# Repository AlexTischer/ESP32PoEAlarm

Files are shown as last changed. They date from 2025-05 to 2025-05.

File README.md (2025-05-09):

# ESP32 PoE Alarm Board

This repository contains all files related to the ESP32-Alarm board project.

## Project Structure

- **Docs/**  
  Project documentation (LaTeX sources, images, generated PDFs, etc.).

- **Resources/**  
  Manuals, datasheets, reference images, and other useful materials.

- **alarm.yaml**  
  Main ESPHome configuration file, defining the firmware behavior for the ESP32.

- **Case v2.step**  
  3D model of the enclosure for the board.

- **ESP32_Alarm_PCB.kicad_sch**  
  Electrical schematic of the board, created with KiCad.

- **ESP32_Alarm_PCB.kicad_pcb**  
  PCB layout of the board, created with KiCad.

- **ESP32_Alarm_PCB.kicad_pro / .kicad_prl / .kicad_dru**  
  KiCad project files and design rule settings.

- **ESP32_Alarm_PCB.step**  
  3D model of the PCB for mechanical integration and visualization.

- **production/**  
  Folder containing production files such as netlists and fabrication archives.

- **ESP32-POE/**  
  Custom KiCad libraries, footprints, and symbols, including modules and screw terminals.

- **ESP32_Alarm_PCB-backups/**  
  Automatic backups of KiCad project files.

- **fabrication-toolkit-options.json**  
  Options for PCB fabrication toolkit and production file generation.

## Notes

- All KiCad project files are compatible with version 8.0 or newer.
- To build and upload the firmware, edit and use `alarm.yaml` with ESPHome.

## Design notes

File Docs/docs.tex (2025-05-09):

\documentclass[a4paper,12pt]{article}

\usepackage[utf8]{inputenc}
\usepackage[T1]{fontenc}
\usepackage[hidelinks]{hyperref}
\usepackage{cite}
\usepackage{listings}
\usepackage{xcolor}
\usepackage{graphicx}
\usepackage{float}
\usepackage{subfig}

\title{Esp32 PoE Alarm Board}
\author{Alessandro Tischer}
\date{\today}

\begin{document}
\maketitle

\newpage
\tableofcontents
\newpage

\section{Introduction}
The aim of this project is to design and develop a Power over Ethernet (PoE) system based on the ESP32 microcontroller \cite{ESP32WiFiBluetooth}, which serves both as an alarm system and as a platform for integrating sensors and actuators into a home automation system.  
The board will communicate via Ethernet with a Home Assistant \cite{assistantHomeAssistant} server, which will manage the alarm system logic and provide centralized control for home automation.  

\subsection{Main Objectives}\label{sec:MainObjectives}
The main objectives are:
\begin{itemize}
    \item Provide reliable detection of state changes of multiple digital and analog inputs such as:
        \begin{itemize}
            \item reed switches for door/window opening,
            \item radar sensors for presence detection,
            \item PIR sensors for motion detection,
            \item gas sensors for gas leak detection,
            \item water level sensors for water leak detection,
        \end{itemize}
    \item Control devices such as sirens and strobe lights by turning them on or off.
    \item Ensure less than a second of latency for sensing and controlling devices. 
    \item Ensure seamless integration with Home Assistant for centralized management and automation.
    \item Guarantee high reliability and continuous operation, even in case of network or power issues.
    \item Allow easy installation, configuration, and future expansion with additional modules or sensors.
    \item Maintain data security and privacy keeping everything local.
    \item Ensure the board is cost-effective and made with readily available components.
\end{itemize}

\subsection{Hardware features}
Key features of the board include:
\begin{itemize}
    \item 16 digital input channels for sensor monitoring,
    \item 2 relay outputs for controlling alarm devices,
    \item 6 analog/digital general-purpose pins for smart sensors or future expansions,
    \item I\textsuperscript{2}C port for additional modules,
    \item Multiple 3V, 5V, and GND pins for powering external devices and expansions.
    \item Power over Ethernet (PoE) support for powering the board and connected devices.
    \item Ethernet connectivity for reliable communication.
\end{itemize}

\newpage
\section{Hardware Structure}
The project is built around a custom PCB designed to accommodate the microcontroller's development board. 

\subsection{Microcontroller}
The ESP32 microcontroller is the heart of the board, providing the necessary processing power and connectivity options. In particular, an Olimex ESP32-POE board \cite{olimexESP32POEOpenSource} was chosen for this project, since it is a low-cost, open-source board with built-in PoE support, which simplifies the design and reduces the number of components needed in the PCB. 

\subsection{Power Supply}
The Olimex ESP32-POE is equipped with a LiPo battery connector and charger, which allows the board to be powered by a battery in case of power failure (even though this won't be likely to happen in the scenario this board was first designed for since the board will be powered by a PoE switch that is connected to a UPS). The battery is charged when the board is powered by PoE, and its voltage can be monitored by the microcontroller. 
This specific development board was chosen against its ISO version, the ESP32-POE-ISO, which has an isolated PoE module. The reason for this choice is that the ISO version is a little bit more expensive, and has a lower power budget. The non ISO version, in fact, can output up to 4W of power to external devices via its 3.3V and 5V pins. This is useful for powering sensors and other devices connected to the board, without the need for additional power supplies. 

\subsection{Logic input/output operations}
The large number of required digital input/outputs could not be satisfied by the Olimex ESP32-POE board alone, as several of its GPIO pins are reserved for the PoE module, reset, and other functions. Two main solutions were considered:
\begin{itemize}
    \item The use of a GPIO expander, such as the MCP23017 \cite{MCP23017}, which communicates with the ESP32 via I\textsuperscript{2}C. This approach is highly flexible and allows for the addition of further GPIOs with minimal changes to the design. However, it requires additional components, a more complex design, and limits the expanded I/Os to digital operations only.
    \item The use of a diode matrix connected to the available GPIOs. This solution enables the utilization of all available GPIOs on the Olimex board, supporting both digital and analog operations. Its drawbacks include increased software complexity, more demanding soldering operations, and a limitation to a maximum of 36 I/Os (using all 12 available GPIOs for the matrix) or 16 I/Os (using 8 GPIOs).
\end{itemize}

The first solution was chosen, as it is easier to implement and the lack of analog functionality on the additional I/Os is not a limitation for this project. For example, reed switch sensors are digital-only, and many other sensors can operate in a simple mode where a pin is pulled high or low depending on the sensor state. Furthermore, the GPIO expander requires only two GPIOs for operation, leaving the remaining pins available for other purposes, such as analog functions or digital communication protocols (e.g., I\textsuperscript{2}C, UART, or SPI). Finally, the I\textsuperscript{2}C bus used for communication with the GPIO expander can be shared with other I\textsuperscript{2}C devices.

\subsection{Relay outputs}
The board features two relay outputs, which can be used to control devices such as sirens or strobe lights. The relays are controlled by the ESP32 GPIOs and can be activated or deactivated based on the state of the inputs or commands received from Home Assistant. The relays chosen for this project are the Omron G5V-1-DC5 \cite{G5V1DC5}, which are compact and suitable for low-power applications.
These relays are designed for low-voltage DC and AC applications, making them ideal for controlling alarm devices. They have a coil voltage of 5VDC and can be activated with a current of 30mA. The relays can switch loads up to 1A at 24V DC or 0.5A at 125V AC, providing sufficient power for most alarm devices.

\newpage
\section{Software Structure}
The software for the ESP32 PoE Alarm Board is developed using ESPHome \cite{ESPHomeSmartHome}, an open-source platform designed for creating custom firmware for microcontrollers. ESPHome provides a highly modular and configurable framework, enabling seamless integration with Home Assistant.

\subsection{Configuration File}
The core of the software is a YAML configuration file, which defines the behavior and features of the board. 

\subsubsection{Device and Platform Settings}
Identification of the board, ESP32 platform, and framework type:

\begin{lstlisting}
    esphome:
      name: alarm
      friendly_name: Alarm

    esp32:
      board: esp32dev
      framework:
        type: arduino
\end{lstlisting}

\subsubsection{Networking}
Configuration of the Ethernet interface (LAN8720), including pin assignments and static IP address.

\begin{lstlisting}
    ethernet:
      type: LAN8720
      mdc_pin: GPIO23
      mdio_pin: GPIO18
      power_pin: GPIO5
      phy_addr: 0
      ip_address: 192.168.1.254
\end{lstlisting}

\subsubsection{Communication}
Enabling of the Home Assistant API, web server, and logging for integration and diagnostics.

\begin{lstlisting}
    logger:

    api:
      encryption:
        key: "{REDACTED}"
      reboot_timeout: 0s

    web_server:
    port: 80
\end{lstlisting}

\subsubsection{I\textsuperscript{2}C Bus}
Definition of the I\textsuperscript{2}C bus for communication with external devices.

\begin{lstlisting}
    i2c:
      sda: GPIO16
      scl: GPIO13
      scan: true
      id: bus_a
\end{lstlisting}

\subsubsection{GPIO Expander}
Configuration of the MCP23017 I/O expander, including its I\textsuperscript{2}C address.

\begin{lstlisting}
    mcp23017:   
      - id: 'mcp23017_hub'
        address: 0x20
\end{lstlisting}

\subsubsection{Inputs}
Declaration of 16 binary sensors connected to the MCP23017, each mapped to a specific pin and configured with pull-up resistors. Only the first will be reported here.

\begin{lstlisting}
    binary_sensor:
      - platform: gpio
        name: "MCP23017 Pin A0"
        pin:
            mcp23xxx: mcp23017_hub
            number: 0
            mode:
            input: true
            pullup: true
            inverted: false
\end{lstlisting}

\subsubsection{Outputs}
Definition of two relay switches, each mapped to a dedicated ESP32 GPIO pin. Only the first will be reported here.

\begin{lstlisting}
    switch:
      - platform: gpio
        name: "Relay1"
        id: relay1
        pin: GPIO32
\end{lstlisting}

\subsubsection{OTA Updates}
Enabling of over-the-air firmware updates with password protection.

\begin{lstlisting}
    ota:
    - platform: esphome
        password: "{REDACTED}"
\end{lstlisting}

\subsection{Firmware Generation}
ESPHome compiles the YAML configuration into a binary firmware file, which is then uploaded to the ESP32 microcontroller. The firmware includes all necessary libraries and drivers for the ESP32, Ethernet, I\textsuperscript{2}C, and GPIO expander. The compilation process also generates a web interface for monitoring and controlling the board.

\subsection{Integration with Home Assistant}
The ESP32 PoE Alarm Board is designed to work seamlessly with Home Assistant. The integration is achieved through the Home Assistant API, which allows the board to send and receive state updates and commands. 
The board sends state updates for all connected sensors and inputs, enabling Home Assistant to monitor the system's status in real-time. Additionally, it can receive commands from Home Assistant to control the relay outputs, allowing for remote activation of alarm devices.

\subsection{Event Handling}
The firmware includes event handling capabilities to respond to state changes and commands. When a sensor state changes (e.g., a door opens or a motion is detected), the firmware generates an event that is sent to Home Assistant. Similarly, when a command is received from Home Assistant (e.g., activate a relay), the firmware processes the command and updates the relay state accordingly.
At this stage, the firmware does not include any logic for handling alarms onboard, as this functionality is designed to be managed by Home Assistant's "Alarmo" integration \cite{faberNielsfaberAlarmo2025}. However, the firmware is designed to be extensible, allowing for future enhancements such as local alarm logic or additional features.
ESPHome provides a well documented component for alarm systems, which can be used to implement local alarm logic in the future \cite{AlarmControlPanel}. This component allows for the definition of alarm states, triggers, and actions, enabling the board to operate independently of Home Assistant if needed.

\subsection{Runtime Behavior}
During operation, the firmware:
\begin{itemize}
    \item Continuously monitors the state of all connected sensors and inputs.
    \item Sends state updates to Home Assistant over the Ethernet connection.
    \item Executes commands received from Home Assistant, such as activating relays.
    \item Logs events and errors for debugging and maintenance purposes.
    \item Handles OTA updates, allowing for easy firmware upgrades without physical access to the board.
    \item Expose a web interface for monitoring and controlling the board, providing real-time status updates and configuration options.
\end{itemize}

This software architecture ensures a robust, flexible, and easily maintainable solution for the ESP32 PoE Alarm Board, meeting the project's objectives and providing a reliable foundation for future enhancements.

\newpage
\section{Sensors}
The board is designed to support a wide range of sensors. For the initial version, the following sensors were selected and tested:
\begin{itemize}
    \item \textbf{Reed Switches}: Used for door/window opening detection.
    \item \textbf{Radar Sensors}: Used for presence detection.
    \item \textbf{PIR Sensors}: Used for motion detection.
\end{itemize}

\subsection{Reed Switches}
Reed switches are simple magnetic sensors that close or open a circuit when exposed to a magnetic field. They are commonly used in security systems to detect the opening of doors or windows. The board supports multiple reed switches, each connected to a digital input pin on the GPIO expander. Since the MCP23017 GPIOs are configured with pull-up resistors, the reed switches are connected in a normally open configuration. When a door or window is opened, the magnetic field is interrupted, causing the reed switch to close and pull the GPIO pin low.

\subsection{Radar Sensors}
For this application, LD2420 radar sensors were chosen \cite{HLKLD242024GhzHumana}. These sensors are capable of detecting motion and presence in a wide area. They work by emitting microwave signals and measuring the reflection from nearby objects. The LD2420 sensors can work in both smart and dumb modes. In dumb mode, the sensor outputs a digital signal indicating the presence of a moving object. In smart mode, the sensor can provide additional information such as distance. To interface with the LD2420 sensors in dumb mode, the board uses a digital input pin on the GPIO expander, and powers the sensor via one of the 3.3V and GND pins.
To use the sensor in smart mode, it's possible to use one of the ESP32's pins to communicate with the sensor via UART. 

\subsection{PIR Sensors}
Passive Infrared (PIR) sensors are widely used for motion detection in security systems. They work by detecting changes in infrared radiation emitted by objects in their field of view. The board supports multiple PIR sensors, each connected to a digital input pin on the GPIO expander. Similar to the reed switches, the PIR sensors are connected in a normally open configuration, and the GPIO pins are configured with pull-up resistors. When motion is detected, the PIR sensor closes the circuit, pulling the GPIO pin low.

\newpage
\section{Design and Prototyping}
The design of the board was done using KiCAD, a free and open-source PCB design software \cite{KiCadEDA}.

\subsection{Schematic Design}
The first step in the design process was to create the schematic diagram of the board. The schematic includes all components and connections details. The main components in the schematic are:
\begin{itemize}
    \item ESP32 microcontroller
    \item GPIO expander
    \item Relays
    \item Screw terminals
    \item Transistors
    \item Diodes
    \item Resistors
\end{itemize}

It was possible to find a ready-made footprint and symbol for both the ESP32-POE board, the GPIO expander and the relays, other than all the other components that were built in KiCAD \cite{ESP32POEFootprintSymbol}. This greatly simplified the design process, as it was possible to focus on the connections and functionality of the board rather than creating custom components.

The GPIO expander was connected to the ESP32 via the I\textsuperscript{2}C bus, which uses two pins (SDA and SCL) for communication. The GPIO expander doesn't have pull-up resistors on its I\textsuperscript{2}C pins, so 2.2k$\Omega$ resistors were added between the SDA and SCL pins and VCC.
The expander also needs to be connected to 3.3V and GND.
The expander needs to be configured in hardware to have a specific I\textsuperscript{2}C address, which is done by connecting its address pins to either VCC or GND. In this case, the address was set to 0x00, connecting all the address pins to GND. 
Another connection that the GPIO expander allows is for the interrupt pins, which can be used to notify the ESP32 when a state change occurs on one of the GPIOs. In this case, since ESPHome doesn't support this feature, the interrupt pins were not connected to the ESP32.

The relays are connected to the ESP32 GPIOs through an NPN transistor (2n2222 \cite{PN2222ABU}), which acts as a switch to control the relay coil. The transistor is driven by the GPIO pin through a 1k$\Omega$ resistor, and when the pin is set high, it allows current to flow through the relay coil, activating the relay. A flyback diode (1N4007 \cite{1N4007}) is connected in parallel with the relay coil to protect the transistor from voltage spikes generated when the relay is deactivated.

The screw terminals are used to easily and firmly connect the sensors and devices to the board. Each terminal is connected to a specific GPIO pin on the GPIO expander, to a free GPIO pin on the microcontroller (or to a reusable one, such as the I\textsuperscript{2}C pins), to one of the three pins of each relay, to GND, to 3.3V, or to 5V. 

The following schematic shows the main components and connections of the board:
\begin{figure}[H]
    \centering
    
    \caption{Schematic of the ESP32 PoE Alarm Board}
    \label{fig:schematic}
\end{figure}

\subsection{Component Selection, BOM}
The components used in the design were selected based on their availability and compatibility with the project requirements. The complete Bill of Materials (BOM), for each board, includes:

\begin{itemize}
    \item n.1 Olimex ESP32-POE development board
    \item n.1 Microchip MCP23017 GPIO expander
    \item n.2 Omron G5V-1-DC5 relays
    \item n.2 2n2222 NPN transistors
    \item n.2 1N4007 diodes
    \item n.2 2.2k$\Omega$ resistors (for I\textsuperscript{2}C pull-ups)
    \item n.2 1k$\Omega$ resistors (for transistor base)
    \item n.1 DIP 28 pin socket (for the GPIO expander)
    \item n.2 female 2.54mm 10 pin sockets (for the ESP32)
    \item n.19 5.0mm 3 pin screw terminals
\end{itemize}

\subsection{Breadboard Prototyping}
Before creating the PCB, a breadboard prototype was built to test the design and functionality of the board. The breadboard prototype included all the main components, including the ESP32 microcontroller, GPIO expander, relays, and some of the screw terminals. The prototype was used to test the validity of the schematic design, the functionality of the components, and the capabilities of the integrated LDO regulator to power the board.

The breadboard prototype was also used to test the ESPHome configuration and the integration with Home Assistant. The GPIO expander was successfully configured, and the relays were tested to ensure they could be activated and deactivated correctly. The sensors were also connected to the board, and their state changes were monitored in Home Assistant.

Once the breadboard prototype was tested and validated, the design was ready for the PCB layout.

The following image shows the breadboard prototype of the board:
\begin{figure}[H]
    \centering
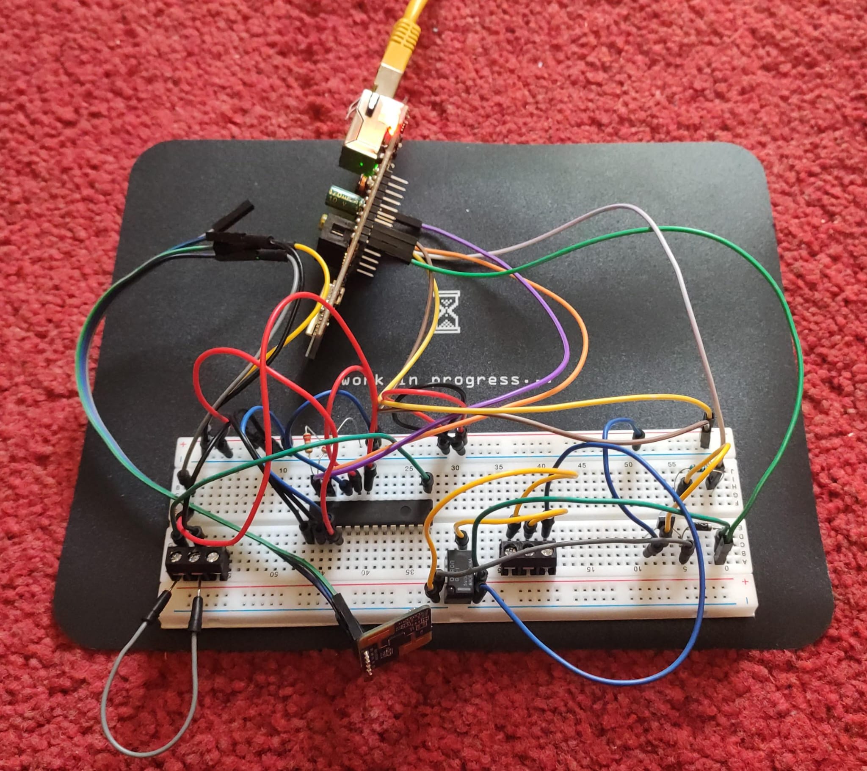
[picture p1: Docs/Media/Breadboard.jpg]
    
    \caption{Breadboard prototype of the ESP32 PoE Alarm Board}
    \label{fig:breadboard}
\end{figure}

\subsection{PCB Layout}

The PCB layout was created using KiCAD, following the schematic design. The layout includes all components, traces, and pads for soldering. The board was designed to be easy to assemble, to mount, to connect to the sensors and devices, to diagnose and repair.
Because of the last point, the board wasn't targeted to be as small as possible, but rather to have all the screw mounts for the sensors on the same side of the board. The other screw terminals are grouped by functionality on the other sides of the board.

All the used components are THD, which makes the soldering process easier and faster, given the low quantity of pieces to be produced. The GPIO expander and the ESP32 are mounted using sockets, which allows for easy replacement in case of failure. This also allow the ESP32 antenna to be further away from the board itself, which improves the signal quality, in case the board were to be used with Wi-Fi connectivity instead of Ethernet, or if ESP32 Bluetooth capabilities were to be exploited.

It was possible to fit all the traces and pads on a two-layer PCB, which was a requirement for the project to be cost-effective. 

The following image shows the PCB layout, with front side traces in red and back side traces in blue. 
\begin{figure}[H]
    \centering
    
    \caption{PCB layout of the ESP32 PoE Alarm Board}
    \label{fig:pcb}
\end{figure}

\subsection{PCB Manufacturing}

The PCB was designed to be manufactured using a low-cost PCB manufacturer, which allows for easy, fast and affordable production of the board and fast shipping \cite{PCBPrototypePCB}.

In KiCAD it is possible to generate the Gerber files needed for the PCB manufacturing, which include all the necessary information for the manufacturer to produce the board. The Gerber files were generated and sent to the manufacturer.

After a few days, the PCBs were received and inspected for any defects. The boards were found to be well manufactured, with no visible defects or issues, so the assembly process could begin.

The following image shows the manufactured PCB:
\begin{figure}[H]
    \centering
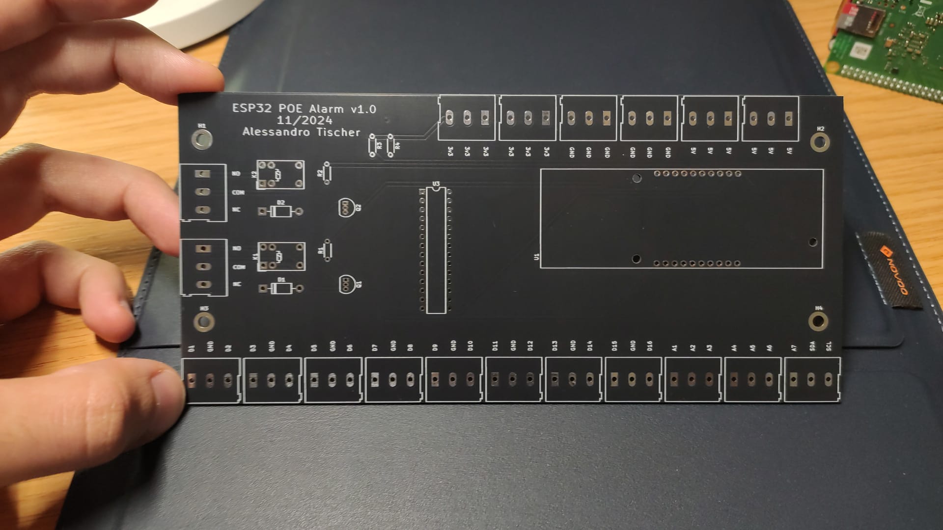
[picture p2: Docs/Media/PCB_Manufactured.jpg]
    
    \caption{Manufactured PCB of the ESP32 PoE Alarm Board}
    \label{fig:manufactured_pcb}
\end{figure}

\subsection{PCB Assembly}

The assembly process was done by hand, using a soldering iron and soldering wire. The components were soldered to the PCB according to the layout, starting with the smallest components and working up to the largest ones. 

Three boards were completely assembled: two for the final application, and one to be kept as a spare in case of failure.
The assembly process was straightforward, but required quite a bit of time and patience, to avoid shorts or cold solder joints.

The following image shows the assembled PCB:
\begin{figure}[H]
    \centering
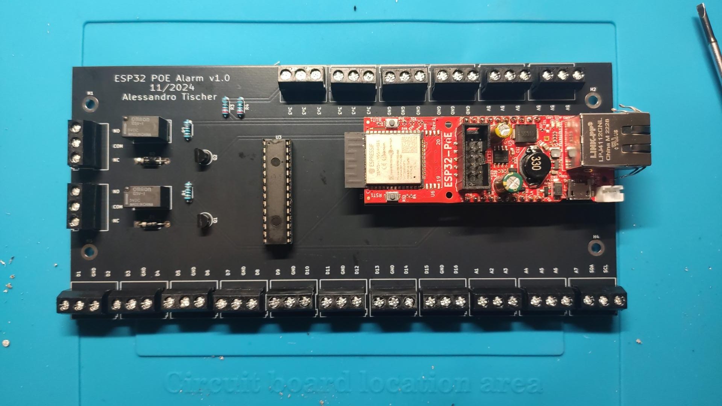
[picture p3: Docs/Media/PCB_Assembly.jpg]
    
    \caption{Assembled PCB of the ESP32 PoE Alarm Board}
    \label{fig:assembled_pcb}
\end{figure}

\newpage
\section{Testing and Validation}

The first testing phase on the complete boards was done to verify the correct operation of the components and the overall functionality of the board. The tests included:

\begin{itemize}
    \item \textbf{Power supply tests:} verifying that the board powers up correctly and that the voltage levels are within the specified range across all the board.
    \item \textbf{Ethernet tests:} verifying that the Ethernet connection is working correctly.
    \item \textbf{Web UI tests:} checking that the web interface is accessible and functional.
    \item \textbf{GPIO tests:} checking that the GPIO expander is communicating with the ESP32.
    \item \textbf{Relay tests:} verifying that the relays can be activated and deactivated correctly.
    \item \textbf{Sensor tests:} checking that the GPIOs could detect a short circuit to ground.
\end{itemize}

The second testing phase was designed to verify that all initial requirements, as defined in Section~\ref{sec:MainObjectives}, were met. Each test corresponds to a specific objective or feature of the board:

\begin{itemize}
    \item \textbf{Reliable detection of state changes:} The board was tested with various digital sensors (reed switches, radar sensors, PIR sensors) to ensure prompt and accurate detection of input changes.
    \item \textbf{Low latency:} The response time between a sensor state change and the corresponding update in Home Assistant is so short that it can barely be perceived, meeting the requirement for low latency.
    \item \textbf{Integration with Home Assistant:} The board was integrated with Home Assistant, and bidirectional communication (state updates and commands) was verified.
    \item \textbf{Reliability and continuous operation:} The board was operated continuously for several days, powered via PoE and connected to a UPS, without any failures or missed events.
    \item \textbf{Ease of installation and expansion:} The modular design, use of screw terminals, and I\textsuperscript{2}C expandability were validated during assembly and sensor connection.
    \item \textbf{Data security and privacy:} Using ESPHome and Home Assistant, the board was configured to operate locally without external cloud services, ensuring intrinsic data security and privacy.
\end{itemize}

All tests were successful, confirming that the ESP32 PoE Alarm Board meets the project's objectives and requirements.

\newpage
\section{Enclosure}
The board was designed to be mounted in a plastic enclosure, which provides physical protection. The enclosure was designed in Autodesk Fusion \cite{AutodeskFusion3D} to be compact and easy to mount, with enough space for the board and the connectors. The enclosure has cutouts for the Ethernet port and the screw terminals, allowing for easy access to the connectors. The enclosure also has mounting holes for securing the board in place.
The enclosure was designed from the beginning keeping in mind that it had to be produced with additive manufacturing using a 3D printer and PLA filament. 
The enclosure was printed in two parts, which were then clicked together to form a complete enclosure. 

The following images show the 3D printed enclosures:
\begin{figure}[H]
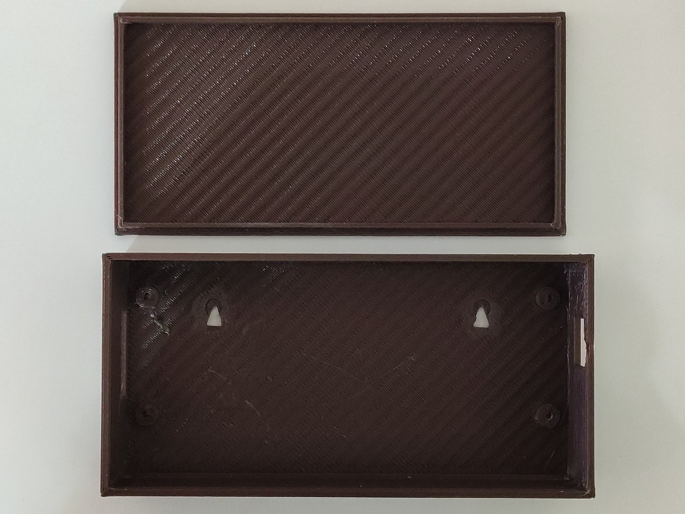
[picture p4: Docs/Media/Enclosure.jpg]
    \subfloat{}\qquad
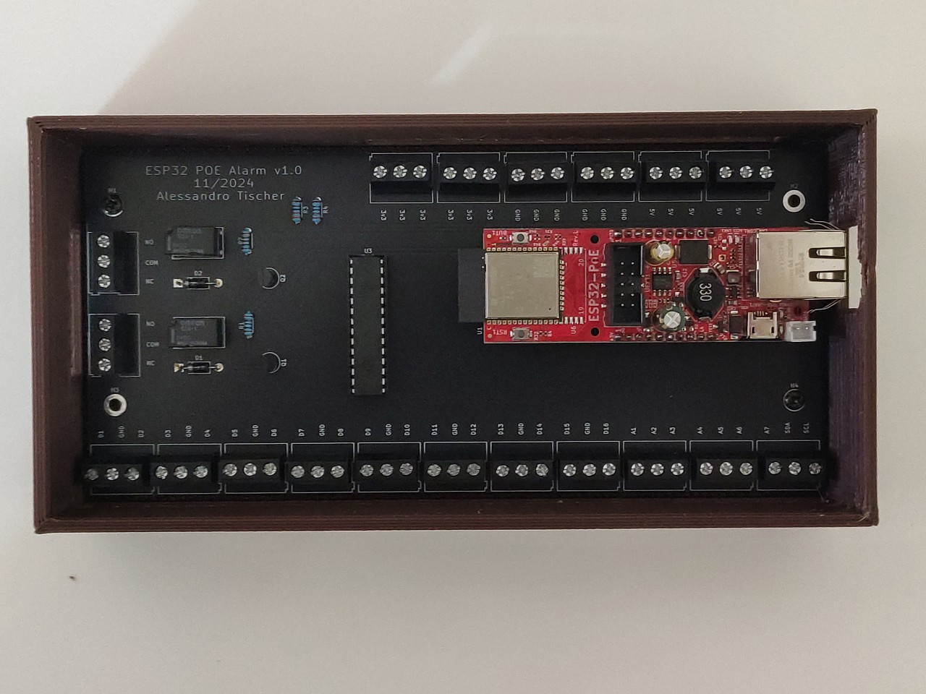
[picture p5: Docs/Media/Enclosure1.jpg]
    \subfloat{}\\
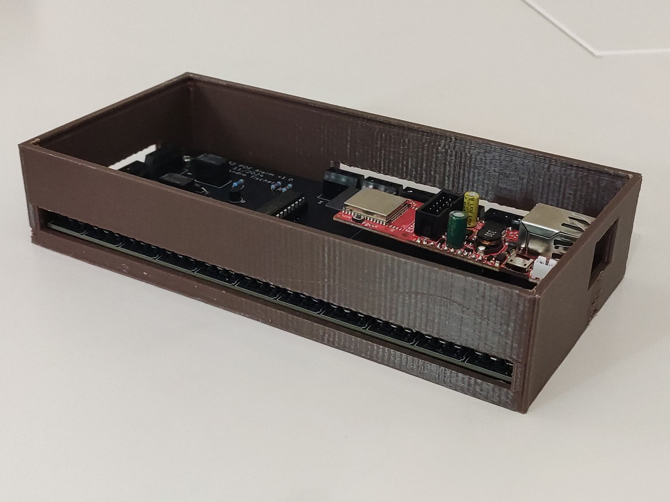
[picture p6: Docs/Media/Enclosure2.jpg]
    \subfloat{}\qquad
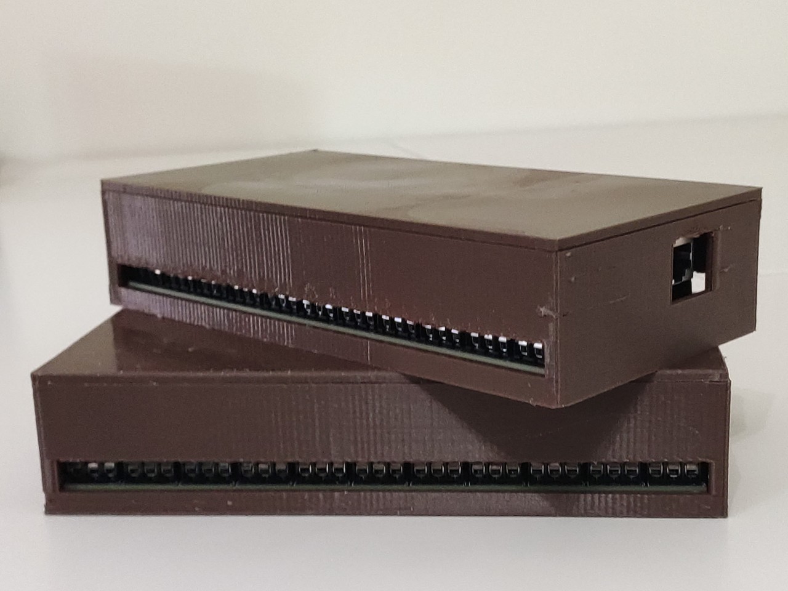
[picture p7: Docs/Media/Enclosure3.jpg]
    \subfloat{}
    \caption{Enclosure of the ESP32 PoE Alarm Board}
    \label{fig:enclosure}
\end{figure}

\newpage
\section{Conclusion}

\subsection{Possible Improvements}
The current design of the ESP32 PoE Alarm Board is functional and meets the initial objectives. However, there are several potential improvements and enhancements that could be made in future iterations:
\begin{itemize}
    \item \textbf{Local Alarm Logic}: Implementing local alarm logic on the board could provide additional functionality and reduce reliance on Home Assistant for alarm management.
    \item \textbf{Integrated ESP32 Module}: Using an integrated ESP32 module instead of a development board could reduce the size and cost of the board, while also improving customization options. For example, designing a custom PoE module, would allow having more power budget for the board.
    \item \textbf{Short Bypass Detection}: In professional alarm systems, a small resistor is connected in series with the reed switch, just before the sensor itself. This resistor is used to detect if the sensor is bypassed by a short circuit made to tamper with the system. Monitoring the resistance on the wire allows detecting if the sensor is bypassed, and to trigger an alarm. This feature was not implemented as the GPIO expander's pins are not connected to an ADC, so it would be impossible to monitor the resistance. In order to keep both the circuit and the software as simple as possible, the GPIO expander was used instead of a more complex solution that would allow monitoring the resistance. However, this feature could be added in the future by using an analog multiplexer or a diode matrix instead of the GPIO expander if the application requires more security.
\end{itemize}

\subsection{Lessons Learned}
The project provided valuable insights into the design and development of a custom PoE alarm system. Key lessons learned include:
\begin{itemize}
    \item The importance of thorough research and component selection to ensure compatibility and functionality.
    \item The benefits of using open-source platforms.
    \item The value of prototyping and testing to validate designs before finalizing the PCB layout.
    \item The significance of clear documentation and organization in the design process to facilitate future modifications and enhancements.
    \item The need for careful consideration of power supply requirements and the impact of component choices on overall system performance.
    \item The importance of designing for ease of assembly and maintenance, including the use of sockets for critical components.
    \item The benefits of using modular designs to allow for future expansion and customization.
    \item The value of testing and validation to ensure the final product meets the initial objectives and requirements.
\end{itemize}

\subsection{Final Remarks}
This project was challenging but rewarding, as it involved researching and learning about various components, software, and design techniques. Particularly demanding were the phases of definition of the requirements, finding and reading the datasheets of the components and checking their compatibility with each other, as well as the design of the schematic and PCB. 

The final product reflects the initial objectives and requirements, providing a reliable and flexible solution for the PoE alarm system. The board is capable of monitoring multiple sensors, controlling devices, and integrating with Home Assistant, making it a valuable addition to any home automation system.

\newpage
\bibliographystyle{unsrturl}
\bibliography{References/Esp32PoEAlarm.bib}

\end{document}

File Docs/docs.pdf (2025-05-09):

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

## Contents

1 Introduction | 4
2 Hardware Structure | 6
3 Software Structure | 8
4 Sensors | 12
5 Design and Prototyping | 14
6 Testing and Validation | 20

2

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

## 1 Introduction

The aim of this project is to design and develop a Power over Ethernet (PoE) system based on the ESP32 microcontroller [1], which serves both as an alarm system and as a platform for integrating sensors and actuators into a home automation system. The board will communicate via Ethernet with a Home Assistant [2] server, which will manage the alarm system logic and provide centralized control for home automation.

### 1.1 Main Objectives

The main objectives are:

| Provide reliable detection of state changes of multiple digital and analog inputs such as: reed switches for door/window opening, radar sensors for presence detection, PIR sensors for motion detection, gas sensors for gas leak detection, water level sensors for water leak detection,
| Control devices such as sirens and strobe lights by turning them on or o.
| Ensure less than a second of latency for sensing and controlling devices.
| Ensure seamless integration with Home Assistant for centralized man- agement and automation.
| Guarantee high reliability and continuous operation, even in case of network or power issues.
| Allow easy installation, conguration, and future expansion with addi- tional modules or sensors.
| Maintain data security and privacy keeping everything local.
| Ensure the board is cost-eective and made with readily available com- ponents.

4

### 1.2 Hardware features

Key features of the board include:

| 16 digital input channels for sensor monitoring,
| 2 relay outputs for controlling alarm devices,
| 6 analog/digital general-purpose pins for smart sensors or future ex- pansions,
| I 2C port for additional modules,
| Multiple 3V, 5V, and GND pins for powering external devices and expansions.
| Power over Ethernet (PoE) support for powering the board and con- nected devices.
| Ethernet connectivity for reliable communication.

5

## 2 Hardware Structure

The project is built around a custom PCB designed to accommodate the microcontroller's development board.

### 2.1 Microcontroller

The ESP32 microcontroller is the heart of the board, providing the necessary processing power and connectivity options. In particular, an Olimex ESP32-POE board [3] was chosen for this project, since it is a low-cost, open-source board with built-in PoE support, which simplies the design and reduces the number of components needed in the PCB.

### 2.2 Power Supply

The Olimex ESP32-POE is equipped with a LiPo battery connector and charger, which allows the board to be powered by a battery in case of power failure (even though this won't be likely to happen in the scenario this board was rst designed for since the board will be powered by a PoE switch that is connected to a UPS). The battery is charged when the board is powered by PoE, and its voltage can be monitored by the microcontroller. This specic development board was chosen against its ISO version, the ESP32-POE-ISO, which has an isolated PoE module. The reason for this choice is that the ISO version is a little bit more expensive, and has a lower power budget. The non ISO version, in fact, can output up to 4W of power to external devices via its 3.3V and 5V pins. This is useful for powering sensors and other devices connected to the board, without the need for additional power supplies.

### 2.3 Logic input/output operations

The large number of required digital input/outputs could not be satised by the Olimex ESP32-POE board alone, as several of its GPIO pins are reserved for the PoE module, reset, and other functions. Two main solutions were considered:

The use of a GPIO expander, such as the MCP23017 [4], which com- municates with the ESP32 via I²C. This approach is highly exible and allows for the addition of further GPIOs with minimal changes to the design. However, it requires additional components, a more complex design, and limits the expanded I/Os to digital operations only.

6

The use of a diode matrix connected to the available GPIOs. This solu- tion enables the utilization of all available GPIOs on the Olimex board, supporting both digital and analog operations. Its drawbacks include increased software complexity, more demanding soldering operations, and a limitation to a maximum of 36 I/Os (using all 12 available GPIOs for the matrix) or 16 I/Os (using 8 GPIOs).

The rst solution was chosen, as it is easier to implement and the lack of analog functionality on the additional I/Os is not a limitation for this project. For example, reed switch sensors are digital-only, and many other sensors can operate in a simple mode where a pin is pulled high or low depending on the sensor state. Furthermore, the GPIO expander requires only two GPIOs for operation, leaving the remaining pins available for other purposes, such as analog functions or digital communication protocols (e.g., I²C, UART, or SPI). Finally, the I²C bus used for communication with the GPIO expander can be shared with other I²C devices.

### 2.4 Relay outputs

The board features two relay outputs, which can be used to control devices such as sirens or strobe lights. The relays are controlled by the ESP32 GPIOs and can be activated or deactivated based on the state of the inputs or commands received from Home Assistant. The relays chosen for this project are the Omron G5V-1-DC5 [5], which are compact and suitable for lowpower applications. These relays are designed for low-voltage DC and AC applications, making them ideal for controlling alarm devices. They have a coil voltage of 5VDC and can be activated with a current of 30mA. The relays can switch loads up to 1A at 24V DC or 0.5A at 125V AC, providing sucient power for most alarm devices.

7

## 3 Software Structure

The software for the ESP32 PoE Alarm Board is developed using ESPHome [6], an open-source platform designed for creating custom rmware for microcontrollers. ESPHome provides a highly modular and congurable framework, enabling seamless integration with Home Assistant.

### 3.1 Conguration File

The core of the software is a YAML conguration le, which denes the behavior and features of the board.

3.1.1 Device and Platform Settings

Identication of the board, ESP32 platform, and framework type:

| esphome : name : alarm friendly_name : Alarm e sp32 : board : esp32dev framework : type : a rduino
3.1.2 | Networking

Conguration of the Ethernet interface (LAN8720), including pin assignments and static IP address.

| e t h e r n e t : type : LAN8720 mdc_pin : GPIO23 mdio_pin : GPIO18 power_pin : GPIO5 phy_addr : 0 ip_add re s s : 1 9 2 . 1 6 8 . 1 . 2 5 4
3.1.3 | Communication

Enabling of the Home Assistant API, web server, and logging for integration and diagnostics.

| 8

l o g g e r :

a pi :
e n c r y p tio n :
key : "{REDACTED}"
reboot_timeout : 0 s

web_server :
po r t : 80

3.1.4 I²C Bus

Denition of the I²C bus for communication with external devices.

i 2 c :
sda : GPIO16
s c l : GPIO13
scan : t r u e
i d : bus_a

3.1.5 GPIO Expander

Conguration of the MCP23017 I/O expander, including its I²C address.

mcp23017 :
= i d : 'mcp23017_hub '
a d d r e s s : 0 x20

3.1.6 Inputs

Declaration of 16 binary sensors connected to the MCP23017, each mapped to a specic pin and congured with pull-up resistors. Only the rst will be reported here.

bina r y_ sen so r :
= pla tfo rm : g pio
name : "MCP23017 Pin A0"
pin :
mcp23xxx : mcp23017_hub
number : 0
mode :
i n pu t : t r u e

9

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

3.1.7 Outputs

Denition of two relay switches, each mapped to a dedicated ESP32 GPIO pin. Only the rst will be reported here.

swi t c h :
= pla tfo rm : g pio
name : " Relay1 "
i d : r el a y 1
pin : GPIO32

3.1.8 OTA Updates

Enabling of over-the-air rmware updates with password protection.

o ta :
= pla tfo rm : esphome
password : "{REDACTED}"

### 3.2 Firmware Generation

ESPHome compiles the YAML conguration into a binary rmware le, which is then uploaded to the ESP32 microcontroller. The rmware includes all necessary libraries and drivers for the ESP32, Ethernet, I²C, and GPIO expander. The compilation process also generates a web interface for monitoring and controlling the board.

### 3.3 Integration with Home Assistant

The ESP32 PoE Alarm Board is designed to work seamlessly with Home Assistant. The integration is achieved through the Home Assistant API, which allows the board to send and receive state updates and commands. The board sends state updates for all connected sensors and inputs, enabling Home Assistant to monitor the system's status in real-time. Additionally, it can receive commands from Home Assistant to control the relay outputs, allowing for remote activation of alarm devices.

10

### 3.4 Event Handling

The rmware includes event handling capabilities to respond to state changes and commands. When a sensor state changes (e.g., a door opens or a motion is detected), the rmware generates an event that is sent to Home Assistant. Similarly, when a command is received from Home Assistant (e.g., activate a relay), the rmware processes the command and updates the relay state accordingly. At this stage, the rmware does not include any logic for handling alarms onboard, as this functionality is designed to be managed by Home Assistant's "Alarmo" integration [7]. However, the rmware is designed to be extensible, allowing for future enhancements such as local alarm logic or additional features. ESPHome provides a well documented component for alarm systems, which can be used to implement local alarm logic in the future [8]. This component allows for the denition of alarm states, triggers, and actions, enabling the board to operate independently of Home Assistant if needed.

### 3.5 Runtime Behavior

During operation, the rmware:

| Continuously monitors the state of all connected sensors and inputs.
| Sends state updates to Home Assistant over the Ethernet connection.
| Executes commands received from Home Assistant, such as activating relays.
| Logs events and errors for debugging and maintenance purposes.
| Handles OTA updates, allowing for easy rmware upgrades without physical access to the board.
| Expose a web interface for monitoring and controlling the board, pro- viding real-time status updates and conguration options.

This software architecture ensures a robust, exible, and easily maintainable solution for the ESP32 PoE Alarm Board, meeting the project's objectives and providing a reliable foundation for future enhancements.

11

## 4 Sensors

The board is designed to support a wide range of sensors. For the initial version, the following sensors were selected and tested:

| Reed Switches: Used for door/window opening detection.
| Radar Sensors: Used for presence detection.
| PIR Sensors: Used for motion detection.
4.1 | Reed Switches

Reed switches are simple magnetic sensors that close or open a circuit when exposed to a magnetic eld. They are commonly used in security systems to detect the opening of doors or windows. The board supports multiple reed switches, each connected to a digital input pin on the GPIO expander. Since the MCP23017 GPIOs are congured with pull-up resistors, the reed switches are connected in a normally open conguration. When a door or window is opened, the magnetic eld is interrupted, causing the reed switch to close and pull the GPIO pin low.

### 4.2 Radar Sensors

For this application, LD2420 radar sensors were chosen [9]. These sensors are capable of detecting motion and presence in a wide area. They work by emitting microwave signals and measuring the reection from nearby objects. The LD2420 sensors can work in both smart and dumb modes. In dumb mode, the sensor outputs a digital signal indicating the presence of a moving object. In smart mode, the sensor can provide additional information such as distance. To interface with the LD2420 sensors in dumb mode, the board uses a digital input pin on the GPIO expander, and powers the sensor via one of the 3.3V and GND pins. To use the sensor in smart mode, it's possible to use one of the ESP32's pins to communicate with the sensor via UART.

### 4.3 PIR Sensors

Passive Infrared (PIR) sensors are widely used for motion detection in security systems. They work by detecting changes in infrared radiation emitted by objects in their eld of view. The board supports multiple PIR sensors, each connected to a digital input pin on the GPIO expander. Similar to the

12 reed switches, the PIR sensors are connected in a normally open conguration, and the GPIO pins are congured with pull-up resistors. When motion is detected, the PIR sensor closes the circuit, pulling the GPIO pin low.

13

## 5 Design and Prototyping

The design of the board was done using KiCAD, a free and open-source PCB design software [10].

### 5.1 Schematic Design

The rst step in the design process was to create the schematic diagram of the board. The schematic includes all components and connections details. The main components in the schematic are:

| ESP32 microcontroller
| GPIO expander
| Relays
| Screw terminals
| Transistors
| Diodes
| Resistors

It was possible to nd a ready-made footprint and symbol for both the ESP32-POE board, the GPIO expander and the relays, other than all the other components that were built in KiCAD [11]. This greatly simplied the design process, as it was possible to focus on the connections and functionality of the board rather than creating custom components.
The GPIO expander was connected to the ESP32 via the I²C bus, which uses two pins (SDA and SCL) for communication. The GPIO expander doesn't have pull-up resistors on its I²C pins, so 2.2kΩ resistors were added between the SDA and SCL pins and VCC. The expander also needs to be connected to 3.3V and GND. The expander needs to be congured in hardware to have a specic I²C address, which is done by connecting its address pins to either VCC or GND. In this case, the address was set to 0x00, connecting all the address pins to GND. Another connection that the GPIO expander allows is for the interrupt pins, which can be used to notify the ESP32 when a state change occurs on one of the GPIOs. In this case, since ESPHome doesn't support this feature, the interrupt pins were not connected to the ESP32.
The relays are connected to the ESP32 GPIOs through an NPN transistor (2n2222 [12]), which acts as a switch to control the relay coil. The transistor

14 is driven by the GPIO pin through a 1kΩ resistor, and when the pin is set high, it allows current to ow through the relay coil, activating the relay. A yback diode (1N4007 [13]) is connected in parallel with the relay coil to protect the transistor from voltage spikes generated when the relay is deactivated.
The screw terminals are used to easily and rmly connect the sensors and devices to the board. Each terminal is connected to a specic GPIO pin on the GPIO expander, to a free GPIO pin on the microcontroller (or to a reusable one, such as the I²C pins), to one of the three pins of each relay, to GND, to 3.3V, or to 5V.
The following schematic shows the main components and connections of

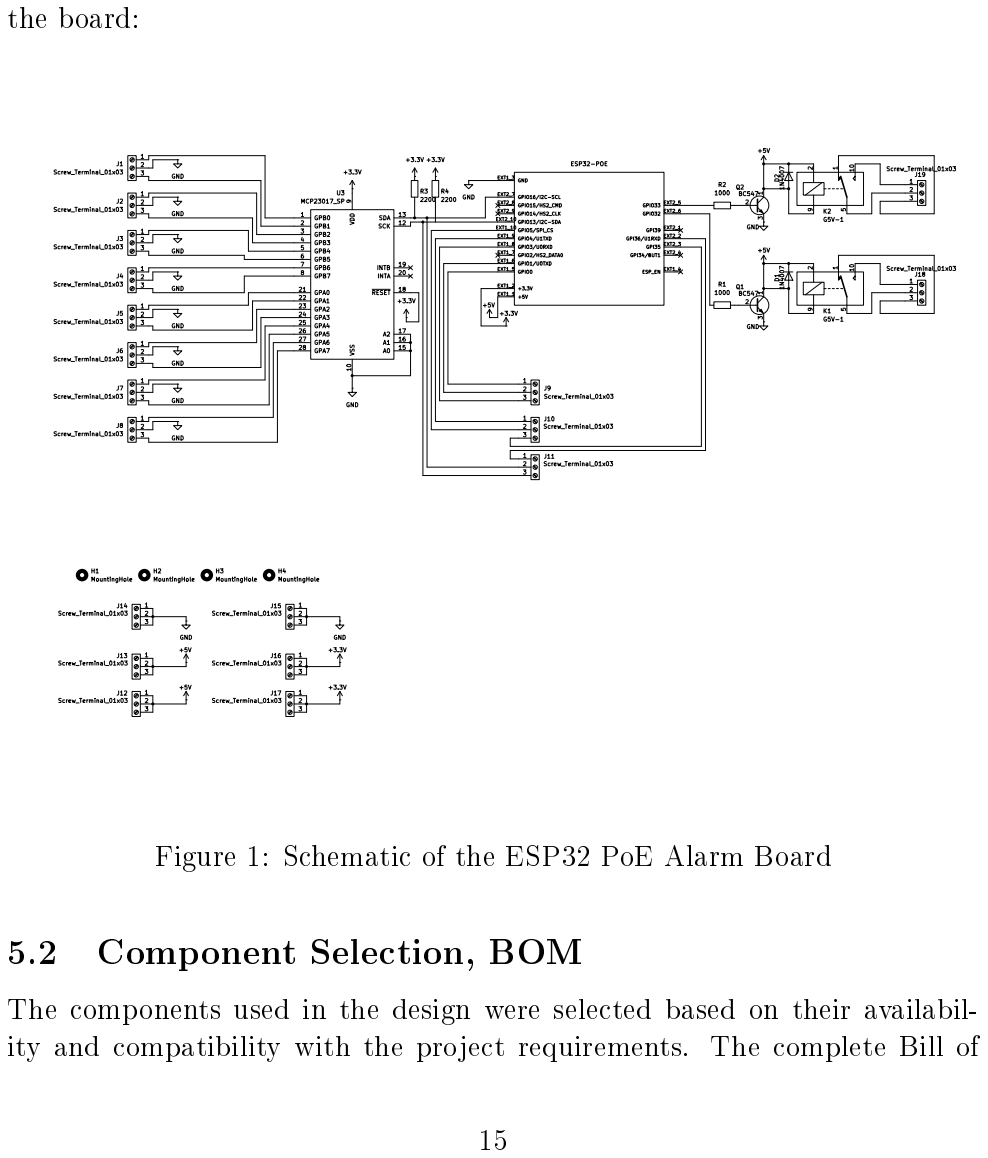
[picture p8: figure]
the board:; Component Selection, BOM

Figure 1: Schematic of the ESP32 PoE Alarm Board

The components used in the design were selected based on their availability and compatibility with the project requirements. The complete Bill of

Materials (BOM), for each board, includes:

| n.1 Olimex ESP32-POE development board
| n.1 Microchip MCP23017 GPIO expander
| n.2 Omron G5V-1-DC5 relays
| n.2 2n2222 NPN transistors
| n.2 1N4007 diodes
| n.2 2.2kΩ resistors (for I²C pull-ups)
| n.2 1kΩ resistors (for transistor base)
| n.1 DIP 28 pin socket (for the GPIO expander)
| n.2 female 2.54mm 10 pin sockets (for the ESP32)
| n.19 5.0mm 3 pin screw terminals
5.3 | Breadboard Prototyping

Before creating the PCB, a breadboard prototype was built to test the design and functionality of the board. The breadboard prototype included all the main components, including the ESP32 microcontroller, GPIO expander, relays, and some of the screw terminals. The prototype was used to test the validity of the schematic design, the functionality of the components, and the capabilities of the integrated LDO regulator to power the board.
The breadboard prototype was also used to test the ESPHome conguration and the integration with Home Assistant. The GPIO expander was successfully congured, and the relays were tested to ensure they could be activated and deactivated correctly. The sensors were also connected to the board, and their state changes were monitored in Home Assistant.
Once the breadboard prototype was tested and validated, the design was ready for the PCB layout.
The following image shows the breadboard prototype of the board:

16


Figure 2: Breadboard prototype of the ESP32 PoE Alarm Board

### 5.4 PCB Layout

The PCB layout was created using KiCAD, following the schematic design. The layout includes all components, traces, and pads for soldering. The board was designed to be easy to assemble, to mount, to connect to the sensors and devices, to diagnose and repair. Because of the last point, the board wasn't targeted to be as small as possible, but rather to have all the screw mounts for the sensors on the same side of the board. The other screw terminals are grouped by functionality on the other sides of the board.
All the used components are THD, which makes the soldering process easier and faster, given the low quantity of pieces to be produced. The GPIO expander and the ESP32 are mounted using sockets, which allows for easy replacement in case of failure. This also allow the ESP32 antenna to be further away from the board itself, which improves the signal quality, in case the board were to be used with Wi-Fi connectivity instead of Ethernet, or if ESP32 Bluetooth capabilities were to be exploited.
It was possible to t all the traces and pads on a two-layer PCB, which was a requirement for the project to be cost-eective.
The following image shows the PCB layout, with front side traces in red

17 and back side traces in blue.

Figure 3: PCB layout of the ESP32 PoE Alarm Board

### 5.5 PCB Manufacturing

The PCB was designed to be manufactured using a low-cost PCB manufacturer, which allows for easy, fast and aordable production of the board and fast shipping [14].
In KiCAD it is possible to generate the Gerber les needed for the PCB manufacturing, which include all the necessary information for the manufacturer to produce the board. The Gerber les were generated and sent to the manufacturer.
After a few days, the PCBs were received and inspected for any defects. The boards were found to be well manufactured, with no visible defects or issues, so the assembly process could begin.
The following image shows the manufactured PCB:

18


Figure 4: Manufactured PCB of the ESP32 PoE Alarm Board

### 5.6 PCB Assembly

The assembly process was done by hand, using a soldering iron and soldering wire. The components were soldered to the PCB according to the layout, starting with the smallest components and working up to the largest ones. Three boards were completely assembled: two for the nal application, and one to be kept as a spare in case of failure. The assembly process was straightforward, but required quite a bit of time and patience, to avoid shorts or cold solder joints.
The following image shows the assembled PCB:


Figure 5: Assembled PCB of the ESP32 PoE Alarm Board

19

## 6 Testing and Validation

The rst testing phase on the complete boards was done to verify the correct operation of the components and the overall functionality of the board. The tests included:

| Power supply tests: verifying that the board powers up correctly and that the voltage levels are within the specied range across all the board.
| Ethernet tests: verifying that the Ethernet connection is working correctly.
| Web UI tests: checking that the web interface is accessible and func- tional.
| GPIO tests: checking that the GPIO expander is communicating with the ESP32.
| Relay tests: verifying that the relays can be activated and deactivated correctly.
| Sensor tests: checking that the GPIOs could detect a short circuit to ground.

The second testing phase was designed to verify that all initial requirements, as dened in Section 1.1, were met. Each test corresponds to a specic objective or feature of the board:

| Reliable detection of state changes: The board was tested with various digital sensors (reed switches, radar sensors, PIR sensors) to ensure prompt and accurate detection of input changes.
| Low latency: The response time between a sensor state change and the corresponding update in Home Assistant is so short that it can barely be perceived, meeting the requirement for low latency.
| Integration with Home Assistant: The board was integrated with Home Assistant, and bidirectional communication (state updates and commands) was veried.
| Reliability and continuous operation: The board was operated continuously for several days, powered via PoE and connected to a UPS, without any failures or missed events.
| 20

| Ease of installation and expansion: The modular design, use of screw terminals, and I²C expandability were validated during assembly and sensor connection.
| Data security and privacy: Using ESPHome and Home Assistant, the board was congured to operate locally without external cloud services, ensuring intrinsic data security and privacy.

All tests were successful, conrming that the ESP32 PoE Alarm Board meets the project's objectives and requirements.

21

## 7 Enclosure

The board was designed to be mounted in a plastic enclosure, which provides physical protection. The enclosure was designed in Autodesk Fusion [15] to be compact and easy to mount, with enough space for the board and the connectors. The enclosure has cutouts for the Ethernet port and the screw terminals, allowing for easy access to the connectors. The enclosure also has mounting holes for securing the board in place. The enclosure was designed from the beginning keeping in mind that it had to be produced with additive manufacturing using a 3D printer and PLA lament. The enclosure was printed in two parts, which were then clicked together to form a complete enclosure.
The following images show the 3D printed enclosures:


Figure 6: Enclosure of the ESP32 PoE Alarm Board

22

## 8 Conclusion

### 8.1 Possible Improvements

The current design of the ESP32 PoE Alarm Board is functional and meets the initial objectives. However, there are several potential improvements and enhancements that could be made in future iterations:

| Local Alarm Logic: Implementing local alarm logic on the board could provide additional functionality and reduce reliance on Home Assistant for alarm management.
| Integrated ESP32 Module: Using an integrated ESP32 module in- stead of a development board could reduce the size and cost of the board, while also improving customization options. For example, de- signing a custom PoE module, would allow having more power budget for the board.
| Short Bypass Detection: In professional alarm systems, a small resistor is connected in series with the reed switch, just before the sensor itself. This resistor is used to detect if the sensor is bypassed by a short circuit made to tamper with the system. Monitoring the resistance on the wire allows detecting if the sensor is bypassed, and to trigger an alarm. This feature was not implemented as the GPIO expander's pins are not connected to an ADC, so it would be impossible to monitor the resistance. In order to keep both the circuit and the software as simple as possible, the GPIO expander was used instead of a more complex solution that would allow monitoring the resistance. However, this feature could be added in the future by using an analog multiplexer or a diode matrix instead of the GPIO expander if the application requires more security.
8.2 | Lessons Learned

The project provided valuable insights into the design and development of a custom PoE alarm system. Key lessons learned include:

| The importance of thorough research and component selection to en- sure compatibility and functionality.
| The benets of using open-source platforms.
| The value of prototyping and testing to validate designs before naliz- ing the PCB layout.
| 23

| The signicance of clear documentation and organization in the design process to facilitate future modications and enhancements.
| The need for careful consideration of power supply requirements and the impact of component choices on overall system performance.
| The importance of designing for ease of assembly and maintenance, including the use of sockets for critical components.
| The benets of using modular designs to allow for future expansion and customization.
| The value of testing and validation to ensure the nal product meets the initial objectives and requirements.
8.3 | Final Remarks

This project was challenging but rewarding, as it involved researching and learning about various components, software, and design techniques. Particularly demanding were the phases of denition of the requirements, nding and reading the datasheets of the components and checking their compatibility with each other, as well as the design of the schematic and PCB. The nal product reects the initial objectives and requirements, providing a reliable and exible solution for the PoE alarm system. The board is capable of monitoring multiple sensors, controlling devices, and integrating with Home Assistant, making it a valuable addition to any home automation system.

24

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

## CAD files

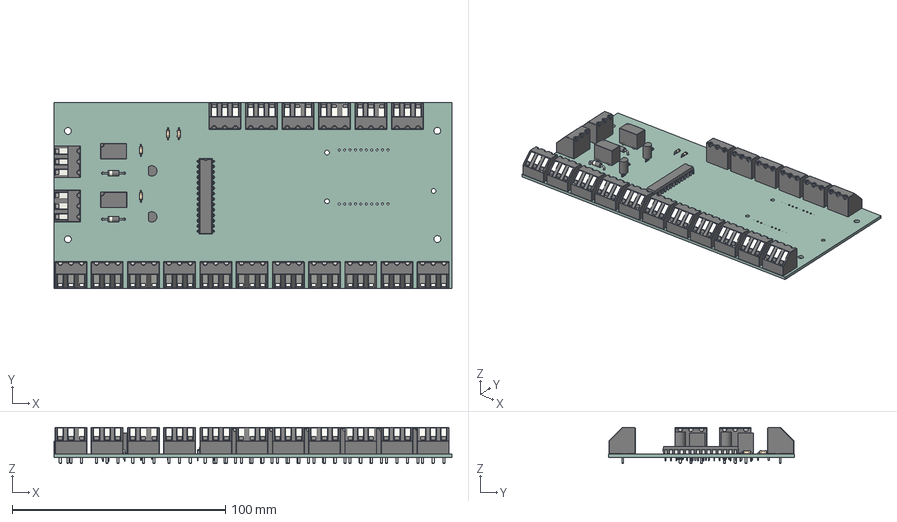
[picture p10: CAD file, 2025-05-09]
ESP32_Alarm_PCB.step
186.8 x 87.1 x 17.1 mm
AK300_3 x 19
Relay_SPDT_Omron_G5V-1 x 2
R_Axial_DIN0204_L36mm_D16mm_P508mm_Horizontal x 4
DIP-28_W7.62mm
D_DO-41_SOD81_P10.16mm_Horizontal x 2
TO-92L_Inline_Narrow x 2
ESP32_Alarm_PCB_PCB

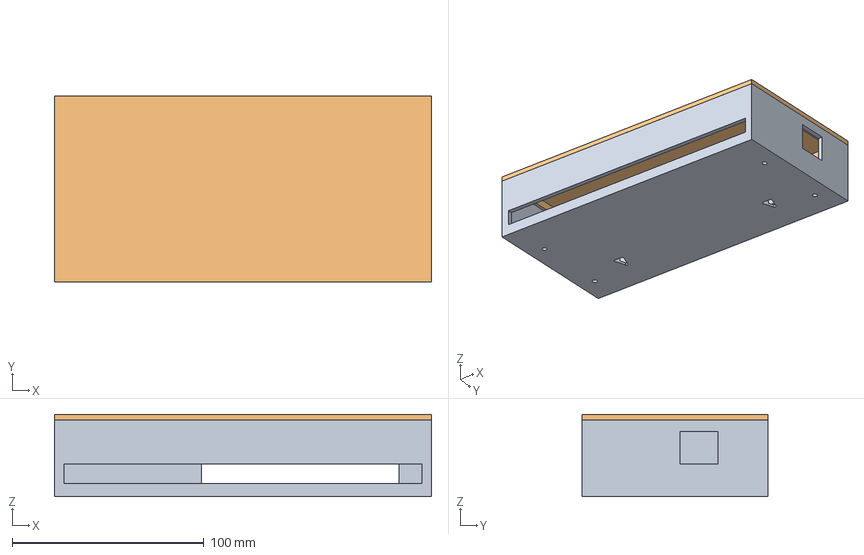
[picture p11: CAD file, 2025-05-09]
Case v2.step
196.8 x 97.1 x 43.0 mm

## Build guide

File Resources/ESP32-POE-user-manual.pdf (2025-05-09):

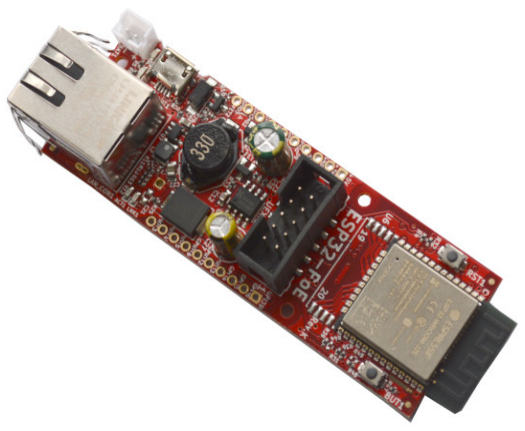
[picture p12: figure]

# ES32-POE ESP32-POE-ISO

# User Manual

Document revision 2.2.

## June 2024

# www.olimex.com

## Table of Contents

## 1. Introduction to ESP32-POE and ESP32-POE-ISO

ESP32-PoE (https://www.olimex.com/Products/IoT/ESP32/ESP32-POE/open-source-hardware) and ESP32-PoE-ISO (https://www.olimex.com/Products/IoT/ESP32/ESP32-POE-ISO/open-source-hardware) are ESP32-powered Wi-Fi/Bluetooth/Ethernet development boards with Power-Over-Ethernet feature. The boards are the perfect addition to any project that requires extra connectivity.
The PoE is currently handled by TPS2375/6 chip (Si3402-B in older revisions) that is IEEE 802.3af-compliant, including pre-standard (legacy) PoE support.
The PoE powering requires at least 37V DC to operate successfully. The board can takes power from the Ethernet cable and can be expanded with sensors and more. Perfect solution for Internet-of-Things projects.
Both ESP32-POE and ESP32-POE-ISO are mature, popular, and well-known products, with wide software support.
+ Important notice: ESP32-PoE (https://www.olimex.com/Products/IoT/ESP32/ESP32-POE/open-source-hardware) has no galvano isolation of Ethernet's power supply, when you program the board via the micro USB connector the Ethernet cable should be disconnected (if you have power over the Ethernet enabled)! Consider using Olimex USB-ISO (https://www.olimex.com/Products/USB-Modules/USB-ISO/) to protect your computer and board from accidental short circuits. Also consider using Olimex ESP32-PoE-ISO (https://www.olimex.com/Products/IoT/ESP32/ESP32-POE-ISO/open-source-hardware) board instead since it is insulated.

## 1.1. ESP32-POE features

- ESP32-WROOM-32E module WiFi + Bluetooth ® + Bluetooth LE module from Espressif Inc (ESP32-WROOM-32UE or ESP32-WROVER-E/IE depending on variant)
- ESP32-WROOM-32E/UE have 4MB flash and 520 KB SRAM
- ESP32-WROVER-E/IE have 4MB Flash 520KB SRAM and 8MB PSRAM
- High reliable industrial grade (-40+85C) variant available (-IND)
- CE-RED and LVD certification
- Original design by OLIMEX Ltd
- Power Over Ethernet negotiation circuit, 802.3-compliant, with minimum operating voltage of 37VDC
- DC-DC converter with 3A at 5V output
- Li-Po battery charger and connector
- Battery level monitor pin on ADC
- External power supply detection pin on ADC
- UEXT connector (https://www.olimex.com/Products/Modules/UEXT/)
- User button
- Reset button
- Micro USB with programmer for ESP32 programming
- MicroSD card
- Two extension connectors 0.1" step spaced at 1"
- PCB dimensions: (80 x 28)mm ~ (3.15 x 1.1)"

## 1.2. ESP32-POE-ISO features

- ESP32-WROOM-32E WiFi + Bluetooth ® + Bluetooth LE module by Espressif Inc (ESP32-WROOM-32UE or ESP32-WROVER-E/IE depending on variant)
- ESP32-WROOM-32E and ESP32-WROOM-32UE have 4MB flash and 520 KB SRAM
- ESP32-WROVER-E/IE have 4MB Flash 520KB SRAM and 8MB PSRAM
- Power Over Ethernet negotiation circuit 802.3 compliant, with minimum operating voltage of 35VDC
- High reliable industrial grade -40+85C available (-IND)
- CE-RED and LVD certification
- Original design by OLIMEX Ltd
- Low power design – 200uA consumption in deep sleep
- Ethernet 100Mb interface with IEEE 802.3 PoE support
- 3000VDC galvanic insulation between the PoE Ethernet part and board's power supply circuit Micro USB connector for ESP32 programming
- MicroSD card working in 1 bit mode
- LiPo battery charger with LiPo battery connector
- Battery level monitor pin on ADC
- External power supply detection pin on ADC
- DC-DC 2W 5V/400mA
- UEXT connector (https://www.olimex.com/Products/Modules/UEXT/)
- User button
- Reset button
- Two extension connectors, 0.1" step spaced at 1"
- PCB dimensions: (98x28)mm ~ (3.8x1)"

## 1.3. PoE standard

ESP32-POE and ESP32-POE-ISO are compliant with the IEEE 802.3af PoE standard and provide up to 15.4 W of DC power (minimum 37V DC and 350 mA). Only 12.95 W are assured to be available at the powered device as some power dissipates in the cable.

ESP32-POE-ISO has 2W DC-DC 5V-5V insulation converter which prevents electrical influence between different sources of power but limits the power usage to 2W only!

## 1.4. The difference between ESP32-POE and ESP32-POE-ISO:

ESP32-POE is not galvanically isolated which means that it’s not safe to connect it to other devices which use non isolated power supply while it is powered. It should have only one power supply and one ground attached to it at a time.
+ This means YOU SHOULD NOT CONNECT ESP32-POE to computer’s USB port while it is powered by Ethernet POE!!! If you connect USB while ESP32-POE is powered by Ethernet you will damage the board or your computer or both. This will also void the warranty!

ESP32-POE-ISO, on the other hand comes with 3000VDC galvanic insulation between the Ethernet POE part and ESP32 power supply, so there is no problem to connect to USB and program or debug while the board is also powered from a PoE source.

## 1.5. The differences between different variants of ESP32-POE and ESP32-POE-ISO:

ESP32-POE (https://www.olimex.com/Products/IoT/ESP32/ESP32-POE/open-source-hardware) and ESP32-POE-ISO (https://www.olimex.com/Products/IoT/ESP32/ESP32-POE-ISO/open-source-hardware) are the base versions with ESP32-WROOM module with 4MB flash memory and nothing extra.

ESP32-POE-EA (https://www.olimex.com/Products/IoT/ESP32/ESP32-POE-EA/open-source-hardware) and ESP32-POE-ISO-EA (https://www.olimex.com/Products/IoT/ESP32/ESP32-POE-ISO-EA/open-source-hardware) have ESP32-WROOM-32UE module with U.FL connector and external antenna attached.

ESP32-POE-IND (https://www.olimex.com/Products/IoT/ESP32/ESP32-POE-IND/open-source-hardware) and ESP32-POE-EA-IND (https://www.olimex.com/Products/IoT/ESP32/ESP32-POE-EA-IND/open-source-hardware) and ESP32-POE-ISO-IND (https://www.olimex.com/Products/IoT/ESP32/ESP32-POE-ISO-IND) and ESP32-POE-ISO-EA-IND (https://www.olimex.com/Products/IoT/ESP32/ESP32-POE-ISO-EA-IND) use industrial grade components suitable for -40+85C operating temperature.

ESP32-POE-WROVER (https://www.olimex.com/Products/IoT/ESP32/ESP32-POE-WROVER/open-source-hardware) and ESP32-POE-ISO-WROVER (https://www.olimex.com/Products/IoT/ESP32/ESP32-POE-ISO-WROVER) comes with ESP32-WROVER-E chip with 4MB flash and 8MB PSRAM, while ESP32-POE-WROVER-EA (https://www.olimex.com/Products/IoT/ESP32/ESP32-POE-WROVER-EA/open-source-hardware) and ESP32-POE-ISO-WROVER-EA (https://www.olimex.com/Products/IoT/ESP32/ESP32-POE-ISO-WROVER-EA) have a WROVER module with extra U.FL connector and external antenna attached.

ESP32-POE-16MB, (https://www.olimex.com/Products/IoT/ESP32/ESP32-POE-16MB/open-source-hardware) ESP32-POE-EA-16MB, (https://www.olimex.com/Products/IoT/ESP32/ESP32-POE-EA-16MB/open-source-hardware) ESP32-POE-ISO-16MB (https://www.olimex.com/Products/IoT/ESP32/ESP32-POE-ISO-16MB/open-source-hardware) and ESP32-POE-ISO-EA-16MB (https://www.olimex.com/Products/IoT/ESP32/ESP32-POE-ISO-EA-16MB/open-source-hardware) feature ESP32-WROOM with 16MB flash memory (as opposed to 4MB).

Features table:

Name/Features | ESP32 module | Flash size, MB | External antenna | Industrial range | PSRAM, MB | Isolated POE
ESP32-POE | ESP32-WROOM-32E-N4 | 4 | - | - | - | -
ESP32-POE-16MB | ESP32-WROOM-32E-N16 | 16 | - | - | - | -
ESP32-POE-EA | ESP32-WROOM-32UE | 4 | Y | - | - | -
ESP32-POE-EA-16MB | ESP32-WROOM-32E-N16 | 16 | Y | - | - | -
ESP32-POE-EA-IND | ESP32-WROOM-32UE | 4 | Y | Y | - | -
ESP32-POE-IND | ESP32-WROOM-32E-N4 | 4 | - | Y | - | -
ESP32-POE-WROVER | ESP32-WROVER-E | 4 | - | - | 8 | -
ESP32-POE-WROVER-EA | ESP32-WROVER-IE | 4 | Y | - | 8 | -
ESP32-POE-ISO | ESP32-WROOM-32E-N4 | 4 | - | - | - | Y
ESP32-POE-ISO-16MB | ESP32-WROOM-32E-N16 | 16 | - | - | - | Y
ESP32-POE-ISO-16MB-IND | ESP32-WROOM-32E-N16 | 16 | - | Y | - | Y
ESP32-POE-ISO-EA | ESP32-WROOM-32UE | 4 | Y | - | - | Y
ESP32-POE-ISO-EA-16MB | ESP32-WROOM-32UE-N16 | 16 | Y | - | - | Y
ESP32-POE-ISO-EA-IND | ESP32-WROOM-32UE | 4 | Y | Y | - | Y
ESP32-POE-ISO-IND | ESP32-WROOM-32E-N4 | 4 | - | Y | - | Y
ESP32-POE-ISO-WROVER | ESP32-WROVER-E | 4 | - | - | 8 | Y
ESP32-POE-ISO-WROVER-EA | ESP32-WROVER-IE | 4 | Y | - | 8 | Y

+ WROVER module uses two extra ESP32 pins for the PSRAM and these pins can’t be used for other purposes. This is important especially if you switch from regular version to WROVER version. This is easily noticeable in the middle of the schematic. GPIO16 and GPIO17 are used by the PSRAM, so GPIO17 that was used for Ethernet clock was replaced by GPIO0 and GPIO16 was replaced by GPIO33. You should do the requires software changes in your code if you switch from ESP32-POE to WROVER version.

## 1.6. Order codes for ESP32-POE and accessories:

ESP32-POE (https://www.olimex.com/Products/IoT/ESP32/ESP32-POE/open-source-hardware) | commercial grade 0-70C board with internal antenna
ESP32-POE-16MB (https://www.olimex.com/Products/IoT/ESP32/ESP32-POE-16MB/open-source-hardware) | commercial grade 0-70C board with internal antenna and 16MB flash
ESP32-POE-EA (https://www.olimex.com/Products/IoT/ESP32/ESP32-POE-EA/open-source-hardware) | commercial grade 0-70C board with external antenna
ESP32-POE-EA-16MB (https://www.olimex.com/Products/IoT/ESP32/ESP32-POE-EA-16MB/open-source-hardware) | commercial grade 0-70C board with external antenna and 16MB flash
ESP32-POE-IND (https://www.olimex.com/Products/IoT/ESP32/ESP32-POE-IND/open-source-hardware) | industrial grade -40+85C board with internal antenna
ESP32-POE-EA-IND (https://www.olimex.com/Products/IoT/ESP32/ESP32-POE-EA-IND/open-source-hardware) | industrial grade -40+85C board with external antenna
ESP32-POE-WROVER (https://www.olimex.com/Products/IoT/ESP32/ESP32-POE-WROVER/open-source-hardware) | commercial grade 0-70C board with 8MB PSRAM and internal antenna
ESP32-POE-WROVER-EA (https://www.olimex.com/Products/IoT/ESP32/ESP32-POE-WROVER-EA/open-source-hardware) commercial grade 0-70C board with 8MB PSRAM and external antenna

BATTERY-LIPO1400mAh (https://www.olimex.com/Products/Power/Lipo-battery/BATTERY-LIPO1400mAh/) Lipo battery 3.7V 1400mAh – note these batteries can be shipped only
| by ground so we can deliver only to EU destinations.
UEXT modules (https://www.olimex.com/Products/Modules/) | Different sensors, relays, LCDs, RTC, GSM, GPS, accessories which can be connected to UEXT connector

## 1.7. Order codes for ESP32-POE-ISO and accessories:

ESP32-POE- (https://www.olimex.com/Products/IoT/ESP32/ESP32-POE-ISO/open-source-hardware) ISO (https://www.olimex.com/Products/IoT/ESP32/ESP32-POE-ISO/open-source-hardware) | commercial grade 0-70C board with internal antenna
ESP32-POE-ISO-16MB (https://www.olimex.com/Products/IoT/ESP32/ESP32-POE-ISO-16MB/open-source-hardware) | commercial grade 0-70C board with internal antenna and 16MB flash
ESP32-POE-ISO-16MB-IND (https://www.olimex.com/Products/IoT/ESP32/ESP32-POE-ISO-16MB-IND/open-source-hardware) | industrial grade -40+85C board with internal antenna and 16MB flash
ESP32-POE-ISO-EA (https://www.olimex.com/Products/IoT/ESP32/ESP32-POE-ISO-EA/open-source-hardware) | commercial grade 0-70C board with external antenna
ESP32-POE-ISO-EA-16MB (https://www.olimex.com/Products/IoT/ESP32/ESP32-POE-ISO-EA-16MB/open-source-hardware) | commercial grade 0-70C board with external antenna and 16MB flash
ESP32-POE- (https://www.olimex.com/Products/IoT/ESP32/ESP32-POE-ISO-IND/open-source-hardware) ISO (https://www.olimex.com/Products/IoT/ESP32/ESP32-POE-ISO-IND/open-source-hardware) -IND (https://www.olimex.com/Products/IoT/ESP32/ESP32-POE-ISO-IND/open-source-hardware) | industrial grade -40+85C board with internal antenna
ESP32-POE- (https://www.olimex.com/Products/IoT/ESP32/ESP32-POE-ISO-EA-IND/open-source-hardware) ISO- (https://www.olimex.com/Products/IoT/ESP32/ESP32-POE-ISO-EA-IND/open-source-hardware) EA-IND (https://www.olimex.com/Products/IoT/ESP32/ESP32-POE-ISO-EA-IND/open-source-hardware) | industrial grade -40+85C board with external antenna
ESP32-POE- (https://www.olimex.com/Products/IoT/ESP32/ESP32-POE-ISO-WROVER/open-source-hardware) ISO- (https://www.olimex.com/Products/IoT/ESP32/ESP32-POE-ISO-WROVER/open-source-hardware) WROVER (https://www.olimex.com/Products/IoT/ESP32/ESP32-POE-ISO-WROVER/open-source-hardware) | commercial grade 0-70C board with 8MB PSRAM, internal antenna
ESP32-POE- (https://www.olimex.com/Products/IoT/ESP32/ESP32-POE-ISO-WROVER-EA/open-source-hardware) ISO- (https://www.olimex.com/Products/IoT/ESP32/ESP32-POE-ISO-WROVER-EA/open-source-hardware) WROVER-EA (https://www.olimex.com/Products/IoT/ESP32/ESP32-POE-ISO-WROVER-EA/open-source-hardware) commercial grade 0-70C board with 8MB PSRAM, external antenna
BATTERY-LIPO1400mAh (https://www.olimex.com/Products/Power/Lipo-battery/BATTERY-LIPO1400mAh/) | Lipo battery 3.7V 1400mAh – note these batteries can be shipped only by ground so we can deliver only to EU destinations.
UEXT modules (https://www.olimex.com/Products/Modules/) | different sensors, relays, LCDs, RTC, GSM, GPS, accessories which can be connected to UEXT connector

## 2. HARDWARE

## 2.1. ESP32-POE layout:

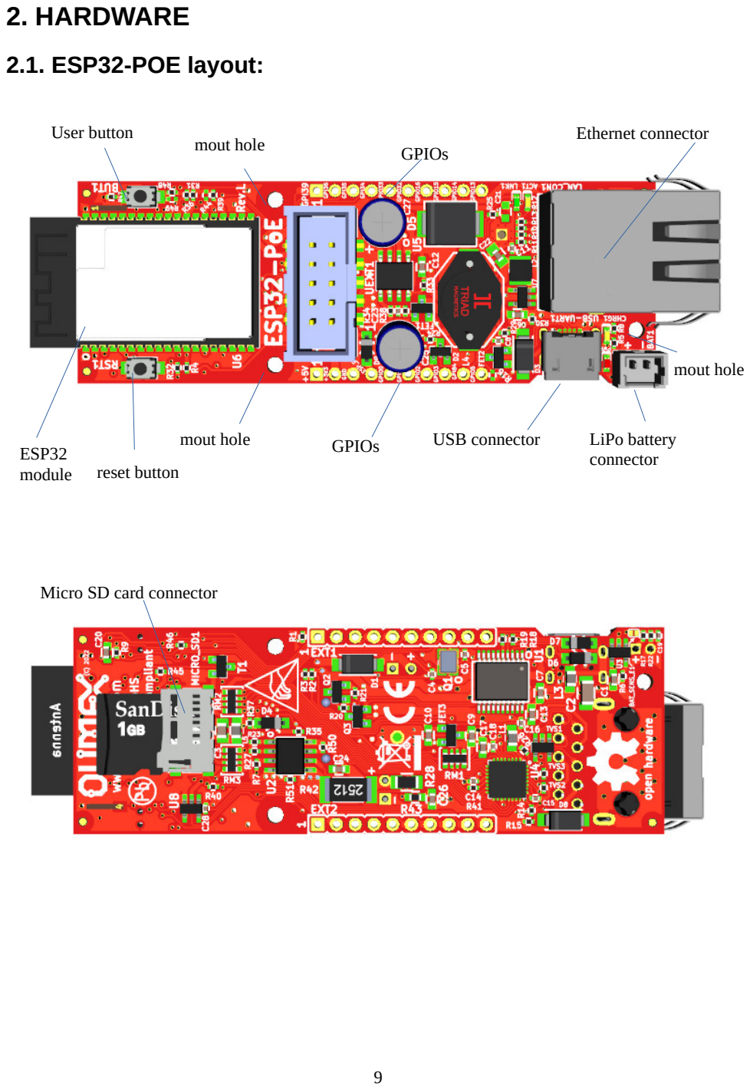
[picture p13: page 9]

User button | mout hole

ESP32
module reset button

mout hole

GPIOs

GPIOs USB connector

Ethernet connector

LiPo battery
connector

mout hole

Micro SD card connector

## 2.2. ESP32-POE GPIOs:

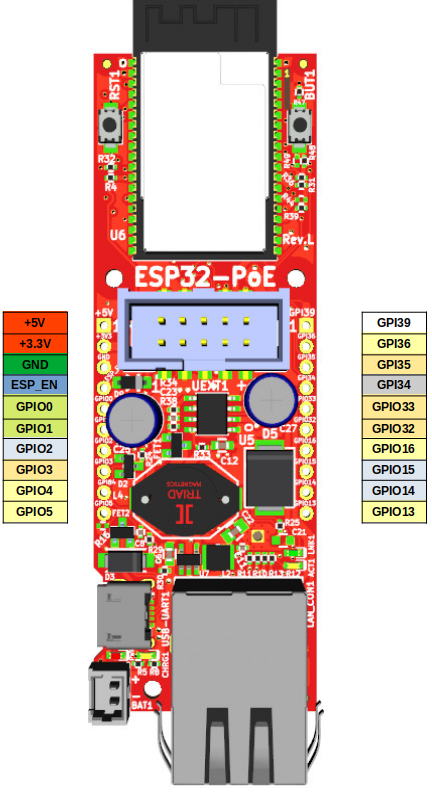
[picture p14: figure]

POWER SUPPLY pads:
+5V 1. Can be input and output; if you use it as input make sure no other 5V sourcesa re applied to the board (having Li-Po battery is OK);
2. When the board is attached to USB or to Ethernet PoE this line can be used ONLY as output
| to power attached peripherals;
3. If you want to use as input i.e. to feed power from external 5V to this line make sure that
| board is not connected to USB!
4. When you use the 5V line as output to power external devices it can provide up to 0.8A @ 5V
| (i.e. 4W) maximum. This includes the 3.3V power output. The combined power draw of +5V output and +3.3V output must not exceed 4W!

+3.3V output which can source up to 0.5A @ 3.3V i.e. (1.65W) Make sure the combined power
| sourced from +3.3V and +5V does not exceed 4W!
GND Ground, the board has common ground.

GPIO pads:
ESP_EN resets the ESP32 module
GPIO0, GPIO2 are boot mode bootstrap pins make sure they are properly configured during power up GPIO1, GPIO3 are used for USB programming, they can be freed up if you won’t further program the boar via USB
GPIO2, GPIO14, GPIO15 are used for the SD-card, if no SD card is preset they are free to use GPIO2, GPIO4, GPIO5, GPIO13, GPIO14, GPIO15, GPIO16, GPIO36 are shared on both UEXT and EXT headers so if you use them on the one connector do not use them at the other
GPI39 is connected to measure external power supply voltage
GPI34 is connected to user button and has 10K pullup
GPI35 is free to use by default but may be connected to measure the LiPo battery voltage if you close BAT_SENS_E1 jumper
+ESP32-POE-WROVER and ESP32-POE-WROVER-EA have no GPIO16 or GPIO17 led out, since they are used for the PSRAM. These are replaced by GPIO33 and GPIO0. GPIO17 being replaced by GPIO0 is crucial for the Ethernet connectivity, since GPIO17/GPIO0 is Ethernet clock out. Make sure to use new assignments in your software if your board variant comes with the WROVER chip.
The ESP32 chip has very advanced multiplexing and you can define any free GPIO pin for I2C, UART, SPI operation as long as you are within the maximum supported (some penalties to SPI's maximum frequency apply, when not using the dedicated pins). Notice that some ESP32 pins can only be inputs. Defining pins is for another job is purely software effort.
For further analysis of pins it is highly recommended to check on the schematic.

## 2.3. ESP32-POE-ISO GPIOs:

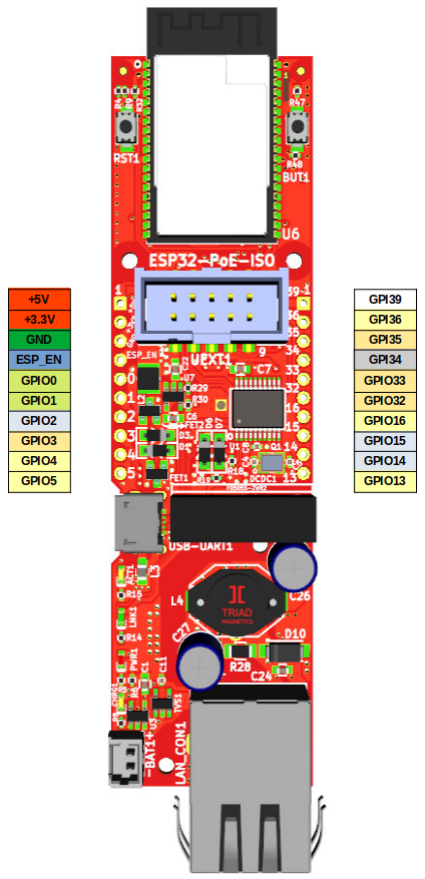
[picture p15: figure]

POWER SUPPLY pads:
+5V 1. Can be used as either input and output. f you use it as input make sure no other 5V source is applied to the board (Li-Po battery is OK);
2. When the board is connected to USB or to Ethernet PoE this line can be used as output and
| power supplement electronic
3. if you want to use as input i.e. to feed power from external 5V to this line make sure board is
| not connected to USB!
4. when you use as output i.e. you feed external electronics from it up to 0.2A @ 5V (i.e. 1W)
| can be sourced maximum. This includes the 3.3V power output. The combined power must not exceed 1W.

+3.3V output which can source up to 0.33A @ 3.3V i.e. (1W) - make sure the combined power
| sourced from +3.3V and +5V does not exceed 1W
GPIO pads:
ESP_EN resets ESP32 module
GPIO0, GPIO1 are used only during programming, after that are free to use
GPIO2, GPIO14, GPIO15 are used for the SD-card, if no SD card they are free to use
GPIO2, GPIO4, GPIO5, GPIO13, GPIO14, GPIO15, GPIO16, GPIO36 are shared on both UEXT and EXT headers so if you use them on the one connector do not use on the other
GPI39 is connected to measure external power supply voltage;
GPI35 is used for battery measurement of the LiPo battery;
GPI34 is connected to used button and has a 10K pullup resistor.

+ESP32-POE-ISO-WROVER and ESP32-POE-ISO-WROVER-EA have no GPIO16 and GPIO17 led out, since they are used for the PSRAM. GPIO16 is replaced by GPIO33. GPIO17 is replaced by GPIO0, this is important for the Ethernet connectivity, since GPIO17/GPIO0 is Ethernet clock out. Make sure to use new assignments if your board variant comes with the WROVER chip.
The ESP32 chip has very advanced multiplexing and you can define any free GPIO pin for I2C, UART, SPI operation as long as you are within the maximum supported (some penalties to SPI's maximum freqncy apply, when not using the dedicated pins). Notice that some ESP32 pins can only be inputs. Defining pins is for another job is purely software effort.
For further analysis of pins it is highly recommended to check on the schematic.

## 2.4. ESP32-POE(-ISO) schematics

This is an open hardware design made with KiCAD. All design files and exports can be found at our GitHub.

ESP32-POE schematic hardware revision L is at GitHub (https://github.com/OLIMEX/ESP32-POE/tree/master/HARDWARE/ESP32-PoE-hardware-revision-L)
ESP32-POE board revision changes are at GitHub (https://github.com/OLIMEX/ESP32-POE/blob/master/HARDWARE/Revision-changes.txt)

ESP32-POE-ISO schematic revision L is at GitHub (https://github.com/OLIMEX/ESP32-POE-ISO/tree/master/HARDWARE/ESP32-PoE-ISO-Rev.L) ESP32-POE-ISO board revision changes are at GitHub (https://github.com/OLIMEX/ESP32-POE-ISO/blob/master/HARDWARE/Hardware-changes-log.txt)

## 2.5. ESP32-POE(-ISO) power supply

ESP32-POE(-ISO) can be powered by 4 sources:
- Ethernet PoE
- USB-micro connector
- Li-Po battery
- EXT1 pin 1 (+5V) but note that this signal is connected to USB 5V signal so when you power via this EXT1 pin you should not connect the board to the USB!
- The standard power consumption of ESP32-POE(-ISO) is between 50mA and 200mA depending on the operation mode. When using power-down modes and Li-Po battery power it can go down to micro amperes.
- Li-Po battery gets automatically charged with about 100mA when external power supply is present. When the LiPo battery is attached and external power supply is missing internal DCDC step-up converter and switching circuit automatically powers ESP32-POE from the battery. 1400mAh battery will provide about 8 hours of stand alone operation.
+The LiPo battery connector is JST 2.0 mm connector and with Olimex’s battery polarity. If you use batteries from other manufacturers please make PLUS and MINUS are connected properly as you may damage the board!
+ Is it safe to have USB and PoE connected and enabled at the same time? If you are using ESP32-POE or any of its variants – no, it is not safe and should be avoided at all costs. If you are using ESP32-POE-ISO or any of its variants – yes, it is safe to have them both attached and enabled.

### 2.5.1. External power sense feature

This allows to detect when the board has external powering. This is helpful if you want to switch between different power modes depending on whether the board is powered from a battery or external power source. By default the external power sense is enabled and it is available on GPI39!
Refer to this Arduino IDE example to see how you can check for the presence external power and check the battery measurement:
https://github.com/OLIMEX/ESP32-POE/blob/master/SOFTWARE/ARDUINO/ESP32_PoE_PowerReading/ESP32_PoE_PowerReading.ino (https://github.com/OLIMEX/ESP32-POE/blob/master/SOFTWARE/ARDUINO/ESP32_PoE_PowerReading/ESP32_PoE_PowerReading.ino)

### 2.5.2. Battery measurement feature

This allows to measure the Li-Po battery’s voltage. This is helpful so you can evaluate when the battery is going to drain out so you can power off the board safely or switch to more conservative power method. In ESP32-POE and its variants the battery measurement features is disabled by default but you can enabled it by soldering together the pads of STM jumper BAT_SENS_E1 jumper, after closing it – it will be routed to GPI35!
In ESP32-POE-ISO and its variants – the battery measurement is enabled and it is available on GPI35! Refer to this Arduino IDE example to see how you can check for external power and check the battery measurement:
https://github.com/OLIMEX/ESP32-POE/blob/master/SOFTWARE/ARDUINO/ESP32_PoE_PowerReading/ESP32_PoE_PowerReading.ino (https://github.com/OLIMEX/ESP32-POE/blob/master/SOFTWARE/ARDUINO/ESP32_PoE_PowerReading/ESP32_PoE_PowerReading.ino)

## 2.6. UEXT connector:

UEXT connector stands for Universal EXTension connector and typically contains +3.3V, GND, UART, I2C, SPI signals.
UEXT is 0.1” 2.54mm step boxed plastic connector. All signals are with 3.3V levels.

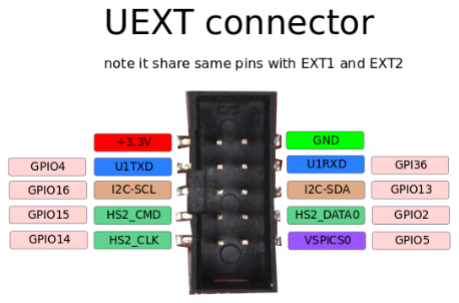
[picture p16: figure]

Olimex has developed number of extension MODULES (https://www.olimex.com/Products/Modules/) compatible with this connector. There are temperature, humidity, pressure, magnetic field, light sensors. Modules with LCDs, LED matrix, relays, Bluetooth, Zigbee, Wi-Fi, GSM, GPS, RFID, RTC, EKG, sensors, and more.

## 2.7. LED description

Board comes with 4 on-board status LEDs. These are not connected to the ESP32 directly and can’t be used as general purpose LEDs.

LED CHRG1 shows whether the Li-Po battery attached to the board is currently charging. When it is off it means that either there is no battery attached or it is already fully charged. Refer to "BL4054/BL4054B" datasheet and check for "CHRGb" port for more detailed information.

LED PWR1 is turned on when there is 5V DC applied to the board. It only actives from external power supply, USB power supply, or PoE powering. It won't turn on when board is powered from a Li-Po battery at BAT1 connector (to conserve energy required to power that LED).

LEDs LNK1 and ACT1 are Ethernet link and activity LEDs. LNK1 is turned on when 100 Mbps speed is detected, and turns off at 10Mbps or less. ACT1 blinks when activity is detected. For more information about their behavior, refer to the manual of "LAN8710A/LAN8710AI" and check the table describing "REGOFF" port (ACT1 is connected to it) and "nINTSEL" port (LNK1 is connected to it).

During USB power up the CHRG1 and PWR1 LEDs should light up.

Important! In order to reduce current consumption the LEDs would remain off when the board is powered from Li-Po battery! Do not count on the LEDs when the board is powered only from a Li-Po battery!

## 3. SOFTWARE:

ESP32-POE and ESP32-POE-ISO are very popular boards and supported by a lot of software tools, among them (there are ready-to-use configs for ESP32-POE and ESP32-POE-ISO):

- Espressif ESP-IDF (https://docs.espressif.com/projects/esp-idf/en/latest/esp32/get-started/)
- Arduino IDE (https://github.com/espressif/arduino-esp32)
- MicroPython (https://micropython.org/download/OLIMEX_ESP32_POE/)
- ESPhome (https://github.com/esphome/bluetooth-proxies/blob/main/olimex-esp32-poe-iso.yaml)
- PlatformIO (https://docs.platformio.org/en/latest/boards/espressif32/esp32-poe.html)

## 3.1. Olimex-made software

We provide some examples for basic functions at our GitHub:

- For Arduino you can find them here:

https://github.com/OLIMEX/ESP32-POE/tree/master/SOFTWARE/ARDUINO

- For ESP-IDF here:

https://github.com/OLIMEX/ESP32-POE/tree/master/SOFTWARE/ESP-IDF

## 4. Frequently asked questions:

- Is it safe to have USB powering and PoE powering connected and enabled at the same time?
- If you are using ESP32-POE or any of its variants – no, it is not safe and should be avoided at all costs.
- If you are using ESP32-POE-ISO or any of its variants – yes, it is safe to have them both enabled.
- Where are I2C, UART, SPI pins exposed?
The ESP32 chip has very advanced multiplexing and you can define any free GPIO pin for I2C, UART, SPI operation as long as you are within the maximum supported (some penalties to SPI's maximum frequency apply, when not using the dedicated pins). Notice that some ESP32 pins can only be inputs. Double check if the pins you want to use are free. Defining pins for another function is a purely software effort.
- I provide 24V to the Ethernet of ESP32-PoE-ISO's but it doesn't seem powered. What is the problem?
TPS2375PW (Si3402) would NOT work with 24V DC. The recommended voltage is 48V DC and the minimum is around 37V DC. For more info refer to TPS2375PW's (Si3402-B's) datasheet.
- I power the board from the Ethernet connector. What current do I have available for additional circuits?
Depends on the board used. If you are using ESP32-POE the PoE circuit can safely provide up to 4W, i.e. 800mA @ 5V. Part of this wattage is used to power the ESP32 module, the battery charger, and other circuits part of the board design; the remaining wattage is available for additional circuits (up to around 600mA). Make sure the total current consumption does not exceed 800mA @ 5V.
If you are using ESP32-POE-ISO the isolated DCDC that we use provides up to 2W, this means 400mA @ 5V, 100mA are reserved for the battery charge (available if no battery is connected) and 100mA are provided for ESP32, which leaves up to 200mA @ 5V for your additional circuits.
- I power the board from the battery connector. The LEDs remain off. Is it broken?
Probably not. This is a low-power design. The LEDs would not turn on when operating on battery to save power. You need other ways to determine if it works or not. For example, something over the serial lines or over the Ethernet (with no PoE enabled else it would get powered from there).

- A specific resistor gets very hot! What is this component? Is it safe? Can I remove it? This is probably the resistor that is required by the IEEE standards. It is used for MPS (maintain power signature). Search online "maintain power signature poe" to get the general idea.

We didn't ensure MPS in the first hardware revisions of the board (e.g. had no resistor in place), but this caused availability problems when using some power saving modes – the board consumed less wattage than PoE equipment can detect, which led to PoE equipment shutting the board off.

If you have soldering experience and the resistor bothers you, you might try desoldering it and see if that effects your setup negatively. Notice that we don't recommend doing so.

- ESP32-PoE and ESP32-POE-ISO don't work well with bauds over 115200. What to do? Some older drivers might have wrong timings, causing worse throughput. Download and install the latest drivers for CH340.
- Help! Ethernet is not working. I use ESP32-POE-WROVER and ESP32-POE-ISO-WROVER
The WROVER module require two addition pins compared to the WROOM module. This required two pin changes – GPIO16 and GPIO17 are used by the PSRAM of the WROVER, so we have replaced GPIO16 with GPIO33 and GPIO17 with GPIO0. The change of GPIO17 affects the Ethernet since it serves as Ethernet clock source. Make sure to replace GPIO17 with GPIO0 in your code or configuration!

## 5. Useful links

The main pages of ESP32-POE and ESP32-POE-ISO are the main hubs for other locations, make sure to first check the product page at our web-site.

ESP32-POE main product page: https://www.olimex.com/Products/IoT/ESP32/ESP32-POE/open-source-hardware

ESP32-POE-ISO main product page: https://www.olimex.com/Products/IoT/ESP32/ESP32-POE-ISO/open-source-hardware

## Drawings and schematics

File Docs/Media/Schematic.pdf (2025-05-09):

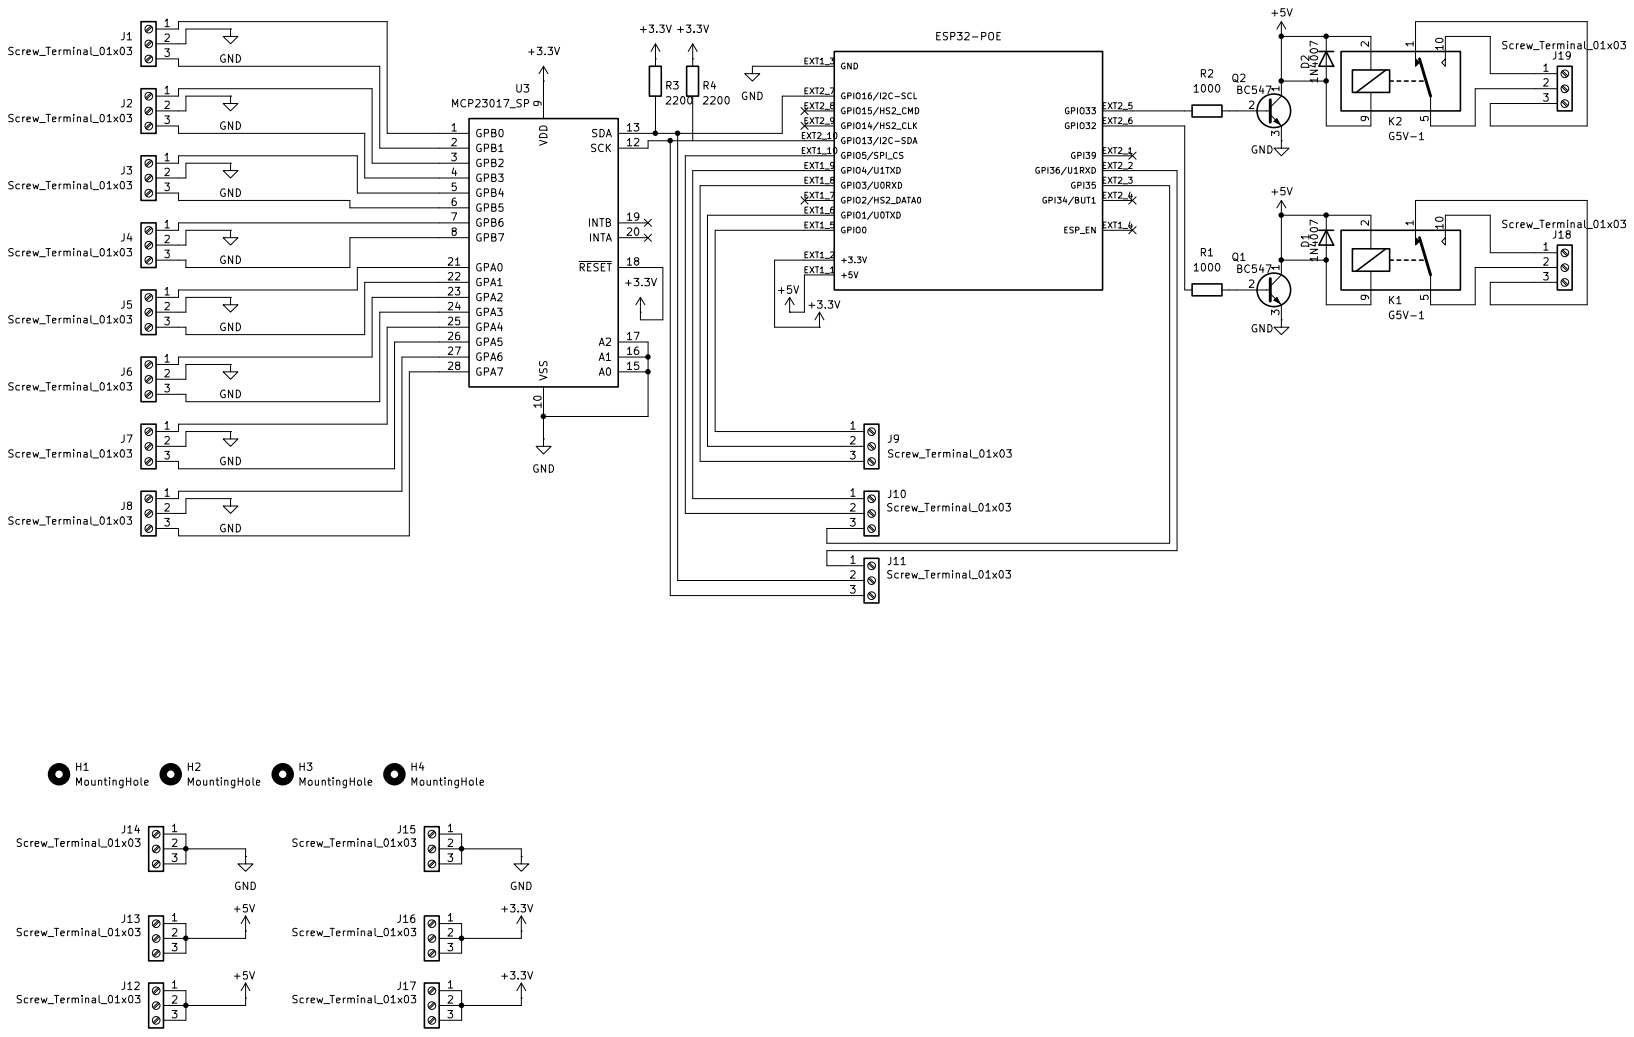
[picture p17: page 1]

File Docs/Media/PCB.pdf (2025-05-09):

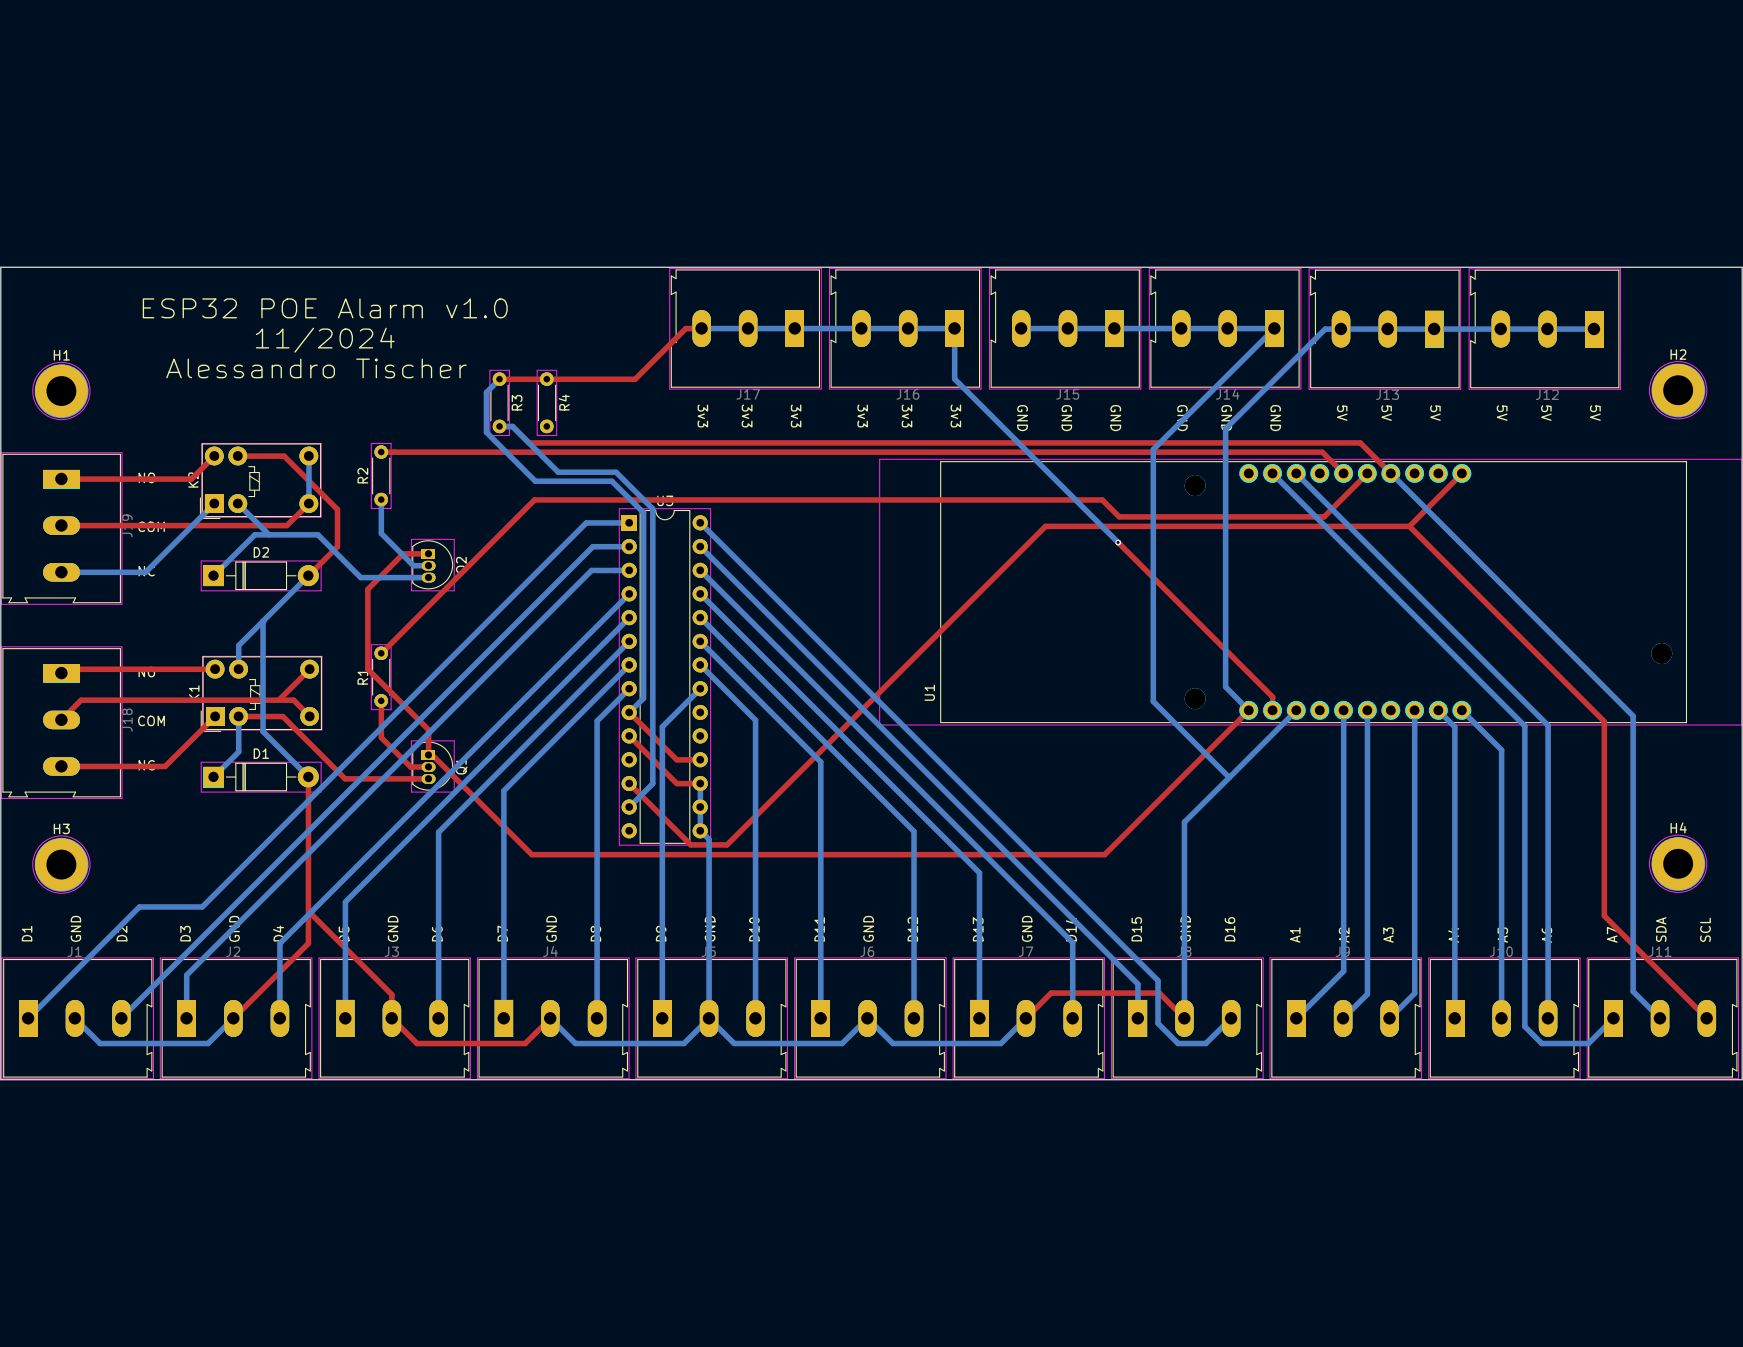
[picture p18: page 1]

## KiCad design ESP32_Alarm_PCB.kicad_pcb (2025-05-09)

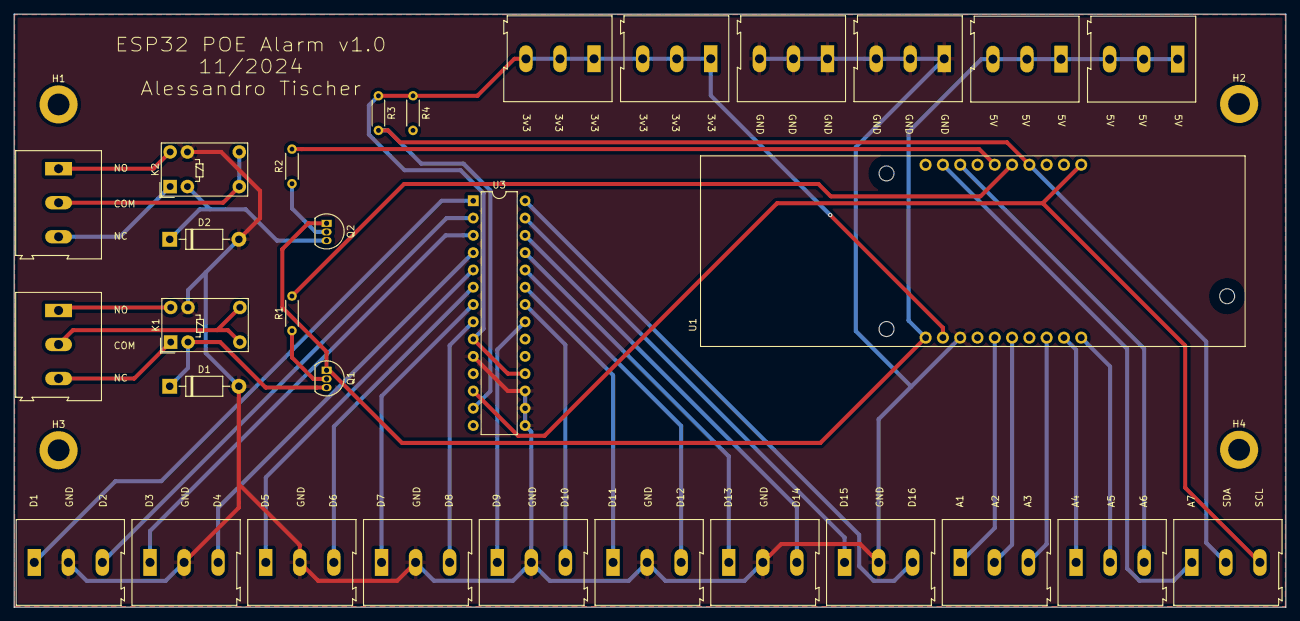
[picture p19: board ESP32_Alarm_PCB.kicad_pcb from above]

Board: 2 copper layers, 186.8 x 87.1 mm, 35 parts (0 on the bottom side), 40 nets.

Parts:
D1, D2: 1N4007; D_DO-41_SOD81_P10.16mm_Horizontal
H1, H2, H3, H4: MountingHole; MountingHole_3.2mm_M3_DIN965_Pad
J1, J2, J3, J4, J5, J6, J7, J8, J9, J10, J11, J12, J13, J14, J15, J16, J17, J18, J19: Screw_Terminal_01x03; ScrewTerminal
K1, K2: G5V-1; Relay_SPDT_Omron_G5V-1
Q1, Q2: BC547; TO-92L_Inline
R1, R2: 1000; R_Axial_DIN0204_L3.6mm_D1.6mm_P5.08mm_Horizontal
R3, R4: 2200; R_Axial_DIN0204_L3.6mm_D1.6mm_P5.08mm_Horizontal
U1: ESP32-POE; MODULE_ESP32-POE
U3: MCP23017_SP; DIP-28_W7.62mm

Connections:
+3.3V: J16.1, J16.2, J16.3, J17.1, J17.2, J17.3, R3.1, R4.1, U1.EXT1_2 (+3.3V), U3.9 (VDD), U3.18 (~RESET)
+5V: J12.1, J12.2, J12.3, J13.1, J13.2, J13.3, Q1.1 (C), Q2.1 (C), U1.EXT1_1 (+5V)
GND: D1.2 (A), D2.2 (A), J1.2, J2.2, J3.2, J4.2, J5.2, J6.2, J7.2, J8.2, J14.1, J14.2, J14.3, J15.1, J15.2, J15.3, K1.9, K2.9, U1.EXT1_3 (GND), U3.10 (VSS), U3.15 (A0), U3.16 (A1), U3.17 (A2)
unnamed: D1.1 (K), K1.2, Q1.3 (E)
unnamed: D2.1 (K), K2.2, Q2.3 (E)
unnamed: J1.1, U3.1 (GPB0)
unnamed: J1.3, U3.2 (GPB1)
unnamed: J2.1, U3.3 (GPB2)
unnamed: J2.3, U3.4 (GPB3)
unnamed: J3.1, U3.5 (GPB4)
unnamed: J3.3, U3.6 (GPB5)
unnamed: J4.1, U3.7 (GPB6)
unnamed: J4.3, U3.8 (GPB7)
unnamed: J5.1, U3.21 (GPA0)
unnamed: J5.3, U3.22 (GPA1)
unnamed: J6.1, U3.23 (GPA2)
unnamed: J6.3, U3.24 (GPA3)
unnamed: J7.1, U3.25 (GPA4)
unnamed: J7.3, U3.26 (GPA5)
unnamed: J8.1, U3.27 (GPA6)
unnamed: J8.3, U3.28 (GPA7)
unnamed: J9.1, U1.EXT1_5 (GPIO0)
unnamed: J9.2, U1.EXT1_6 (GPIO1/U0TXD)
unnamed: J9.3, U1.EXT1_8 (GPIO3/U0RXD)
unnamed: J10.1, U1.EXT1_9 (GPIO4/U1TXD)
unnamed: J10.2, U1.EXT1_10 (GPIO5/SPI_CS)
unnamed: J10.3, U1.EXT2_3 (GPI35)
unnamed: J11.1, U1.EXT2_2 (GPI36/U1RXD)
unnamed: J11.2, R3.2, U1.EXT2_7 (GPIO16/I2C-SCL), U3.13 (SDA)
unnamed: J11.3, U1.EXT2_10 (GPIO13/I2C-SDA), U3.12 (SCK)
unnamed: J18.1, K1.10
unnamed: J18.2, K1.5, K1.6
unnamed: J18.3, K1.1
unnamed: J19.1, K2.10
unnamed: J19.2, K2.5, K2.6
unnamed: J19.3, K2.1
unnamed: Q1.2 (B), R1.1
unnamed: Q2.2 (B), R2.1
unnamed: R1.2, U1.EXT2_6 (GPIO32)
unnamed: R2.2, U1.EXT2_5 (GPIO33)
